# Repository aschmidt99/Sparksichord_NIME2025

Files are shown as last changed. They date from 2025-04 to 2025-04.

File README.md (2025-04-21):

# Sparksichord_NIME2025
 A repo for schematics, CAD, and audiovisual examples to accompany the NIME 2025 Sparksichord conference paper by Adam Schmidt, Jeffrey Snyder, Gian Torrano Jacobs, Joseph Gascho, Joyce Chen, and Andrew McPherson.

 Primary contact: a.schmidt24@imperial.ac.uk

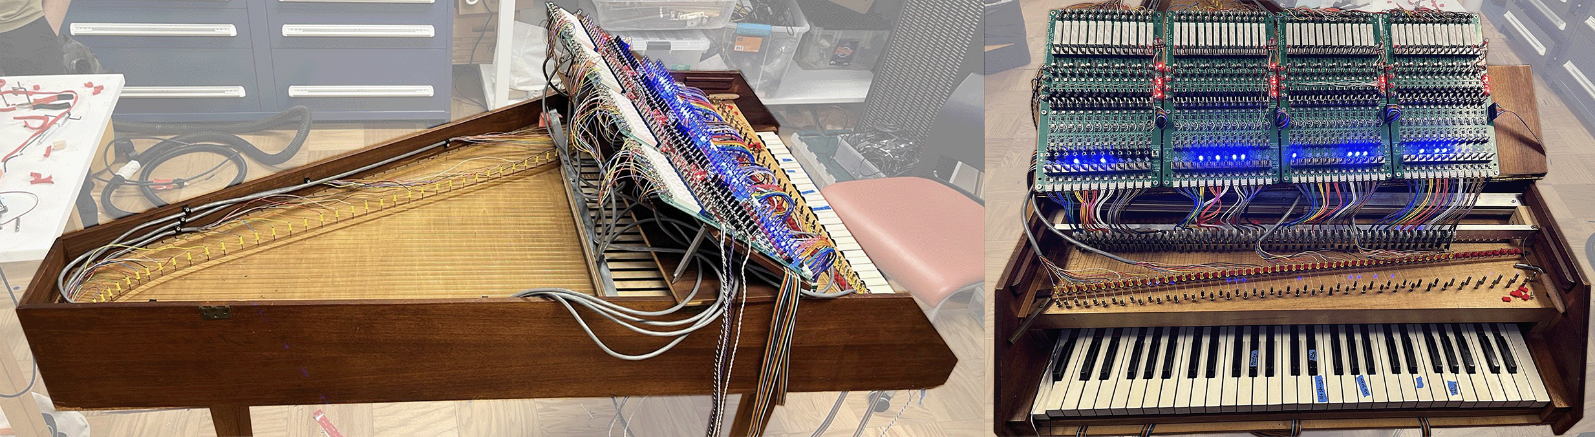
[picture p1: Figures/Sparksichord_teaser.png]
EM_Harpsichord

The Sparksichord is a practical implementation of a 4-octave/48-channel Lorentz Force feedback sustainer system using brass strings, permanent magnets, optical sensors, and custom analog electronics. The Sparksichord is an augmentation of a 1970’s Zuckermann ‘Z-Box’ Harpsichord and uses its own keyboard to control the volume of each string’s feedback/actuation. Here we provide a basic overview of the working principles of the Sparksichord. For a more comprehensive guide to Lorentz Force actuation, please see _The Sparksichord: Practical Implementation of a Lorentz Force Electromagnetic Actuation and Feedback System_.

## Audiovisual example:
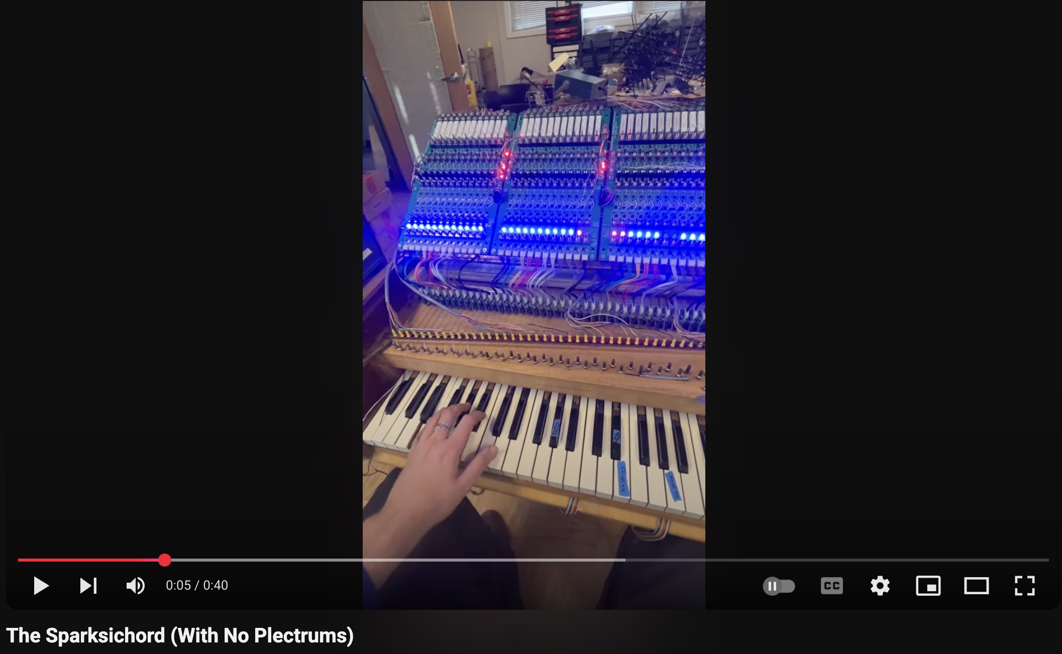
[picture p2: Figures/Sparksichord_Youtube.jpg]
Sparksichord Youtube Clip (https://www.youtube.com/watch?v=jK8IH_FwZ0k)


# Lorentz Force
The cumulative force felt by a charged particle exposed to electric and magnetic fields is known as the _Lorentz Force_. A special case of the Lorentz Force (sometimes referred to as the _Laplace Force_) describes the magnetic force felt by a current-carrying wire exposed to a magnetic field:

$$
\begin{align}
 \mathbf{F} = I \mathbf{L} \times \mathbf{B}
\end{align}
$$

where $\mathbf{F}$ is the force vector felt by the wire, $I$ is the current through the wire, $\mathbf{B}$ is the magnetic field vector, and $\mathbf{L}$ is the length of the wire exposed to the magnetic field.

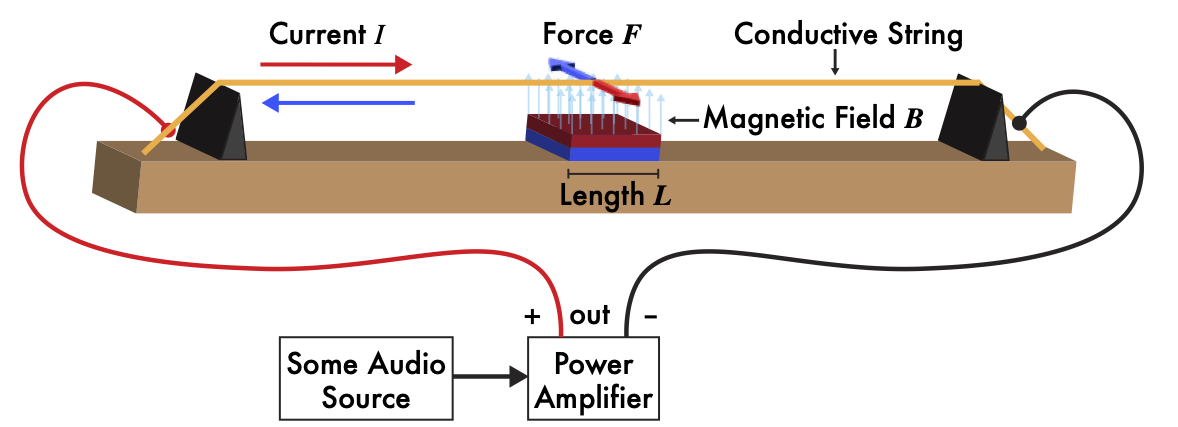
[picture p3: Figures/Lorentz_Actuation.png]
Lorentz Force Overview


Inputing an audio signal to the string such as white noise, you should hear the string vibrate most prominently at its natural resonant frequencies. It is possible to drive a string with an oscillator tuned to match the string’s fundamental frequency, but doing so can be tricky. Depending on the material properties of the actuated string, some of the actuation current may be dissipated as heat in the string’s internal resistance, introducing thermal expansion of the string and causing it to lengthen and reduce its tension. This brings the frequency of the string down causing it to no longer match the frequency of the open-loop actuation signal.

## Heat Buildup \& String Detuning

The resistivity of some conductive metals are displayed in the figure below. Metals such as yellow and red brass are much less resistive than iron and steel, meaning they are more robust to string detuning, though it should be noted that heat treatment or work-hardening of the string material is also a factor, where annealed metal will typically have higher conductivity than a heat-treated metal. Heat-treating or other processes that increase the stength of a metal string are often required for strings to withstand the tensions typically found in musical instruments, so it is fair to assume any wire intended for stringing instruments will have slightly greater resistivity than in the figure below.

Conductivity

The intensity of detuning is proportional to its heat buildup and therefore proportional to the resistivity inherent to the string:

$$
\begin{align}
  Q = I^2Rt
\end{align}
$$

where $Q$ = heat buildup, $I$ = electric current, $R$ = resistance, and $t$ = time. Though this formula suggests that the string may heat up and continue to detune indefinitely as electric current is applied, there is an element of heat dissipation into the surrounding air and any other materials the string is in contact with.  In other words, for a real system, the detuning effect from heat buildup eventually finds equilibrium with the heat dissipation, stabilizing the tuning for a given electric current at a given room temperature.

# Lorentz Force Feedback via Optical Sensor
An optical sensor (in our case, the ITR20403) can be used to sense the string's position. If this signal is sent back into the string via a power amplifier, the string should begin to feedback.
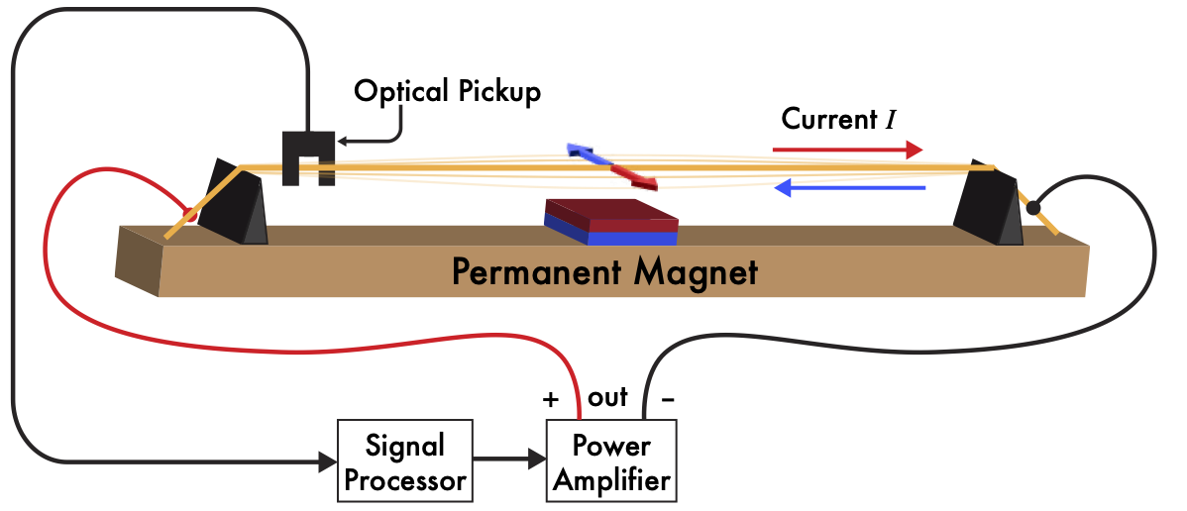
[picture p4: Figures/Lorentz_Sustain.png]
Lorentz Force Feedback via Optical Sensor


On the Sparksichord, an array of 48 sensors was placed above the strings.
Optical Sensor Array

# Dynamic Control Via Amplitude Limitation
We can control the feedback volume by introducing a voltage-controlled limiter. On the Sparksichord, the limiter control signal can from the instrument's own keys (see next section), an onboard potentiometer, or an external control voltage source.
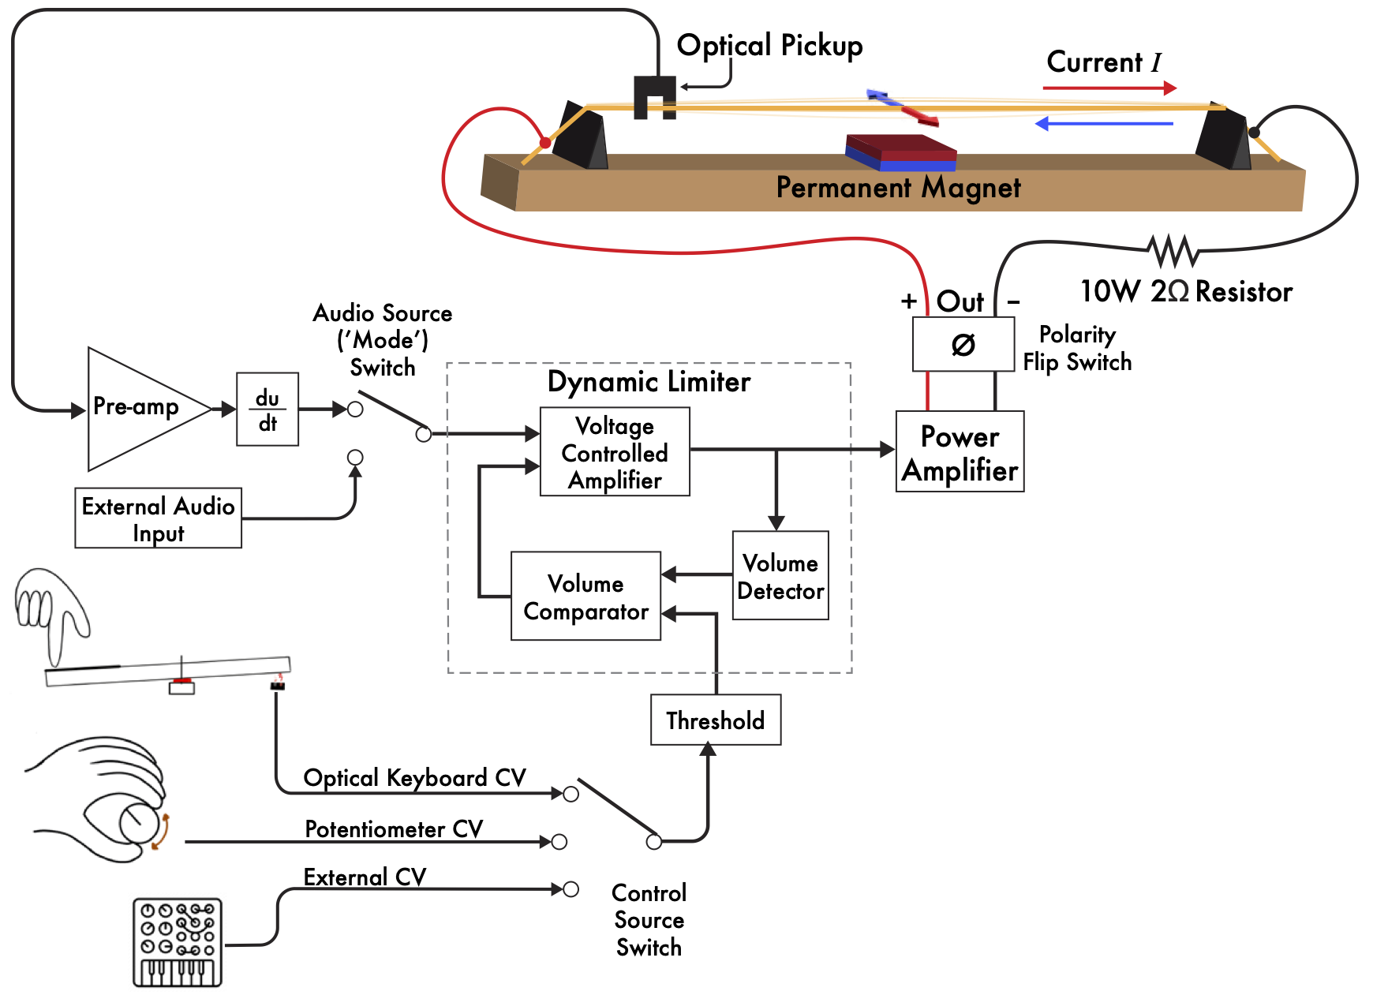
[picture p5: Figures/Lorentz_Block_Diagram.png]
Amplitude Limitation


# Controlling Feedback with Keyboard
To capture how far each key is pressed (to set each limiter circuit's threshold value), we use an array of QRD1114 Optical sensors placed at the back of the keyboard:
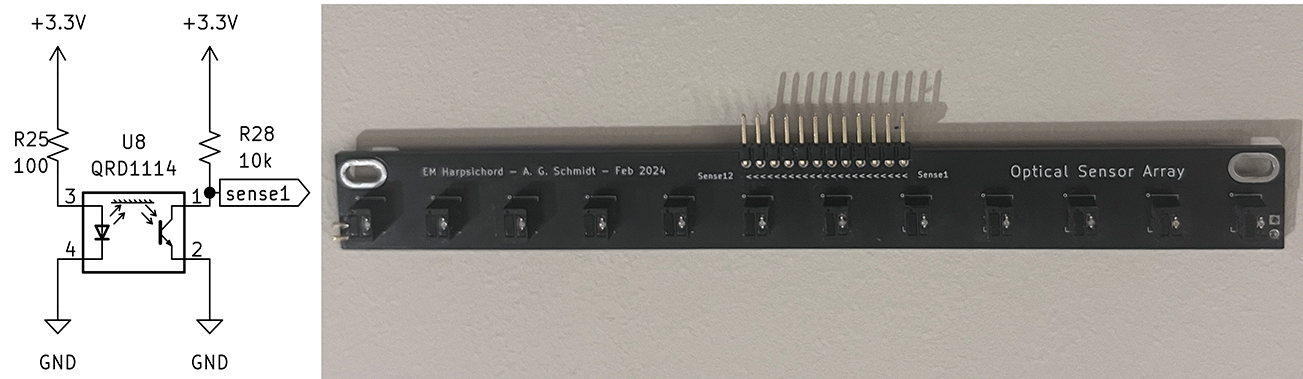
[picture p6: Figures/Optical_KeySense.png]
Optical Keyboard Sensors

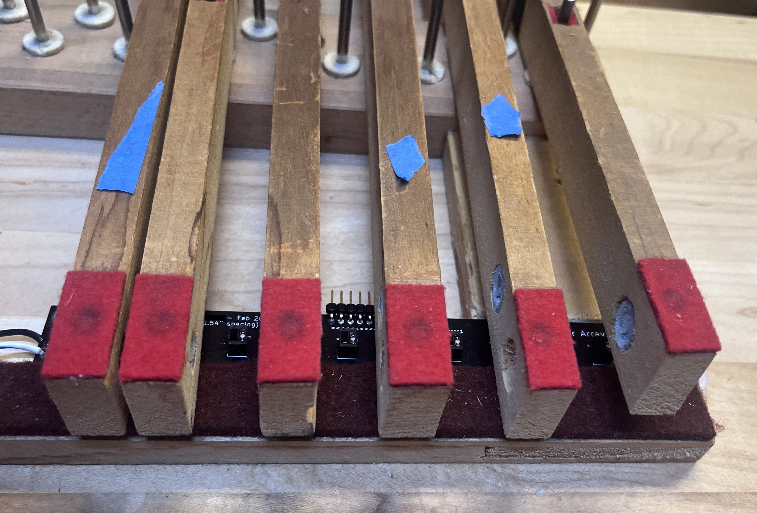
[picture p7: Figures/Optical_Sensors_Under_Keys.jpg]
Optical Sensors Under Keys


# 12-Channel PCB
There are four of these 12-channel sustainer control boards on the Sparksichord:
Optical Sensors Under Keys

# Magnet Placement
Running AC signal through a string doesn't make the string vibrate unless there is a magnetic field nearby. To create a relatively uniform magnetic field for all of the strings, we created a rail that holds 24 N52 Neodymium magnets in uniformly-spaced slots. The position of each magnet can be adjusted to find a desirable feedback timbre:
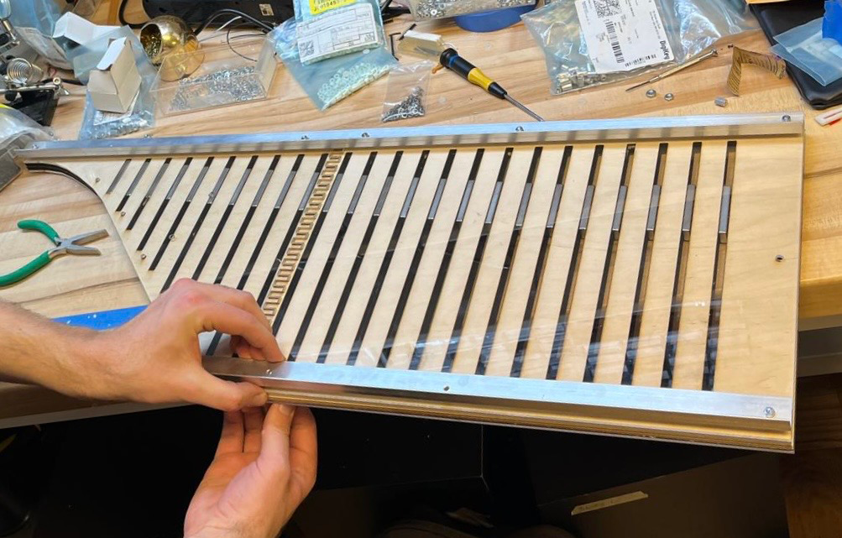
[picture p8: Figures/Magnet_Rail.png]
Magnet Rail

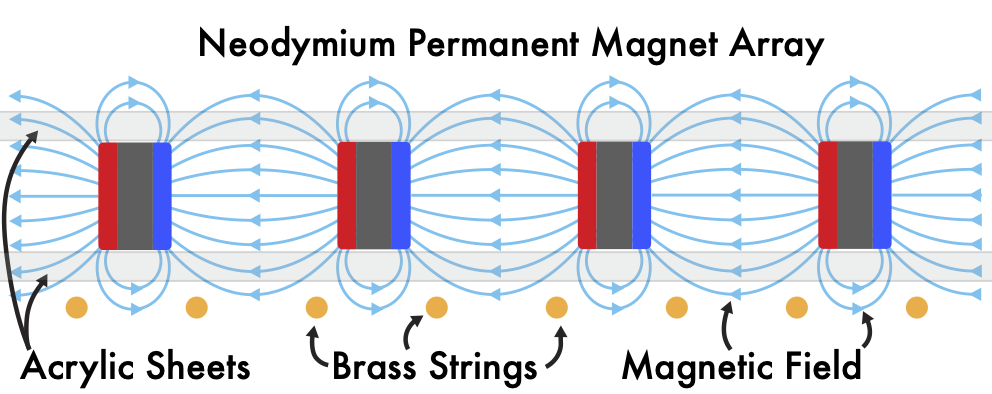
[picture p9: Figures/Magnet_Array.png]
Magnetic Field


# Acknowledgements
This work was supported by a UKRI Frontier Research (Consolidator) grant (EP/X023478/1) “RUDIMENTS: Reflective Understanding of Digital Instruments as Musical Entanglements” and by the Royal Academy of Engineering under the Research Chairs and Senior Research Fellowships scheme.
Early development of this work was supported in part by the University of Michigan Organ Department, University of Michigan ArtsEngine Arts Integrative Interdisciplinary Research (AiiR) Grant, and the University of Michigan EXCEL Enterprise Grant.

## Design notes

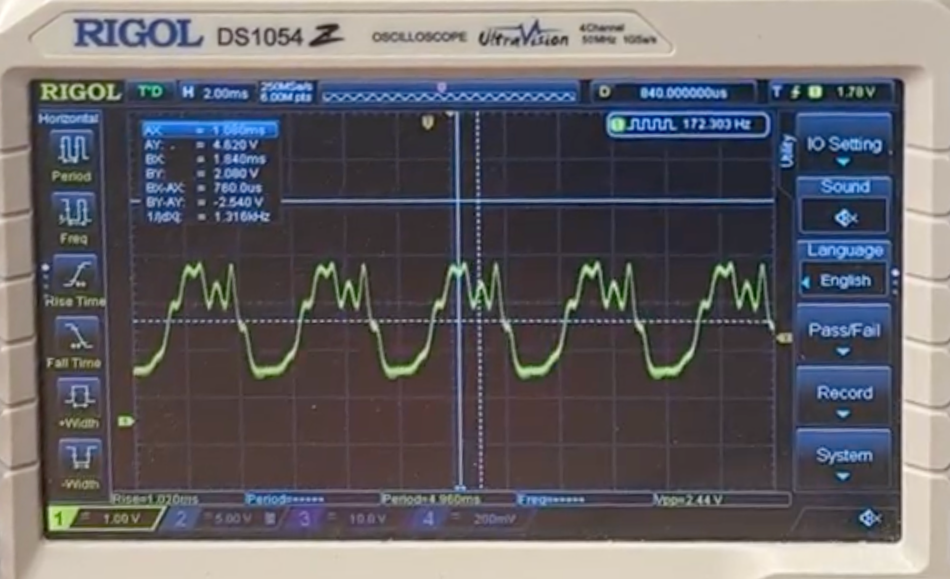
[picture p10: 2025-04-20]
Figures/OpticalSensorDuringFeedback.png

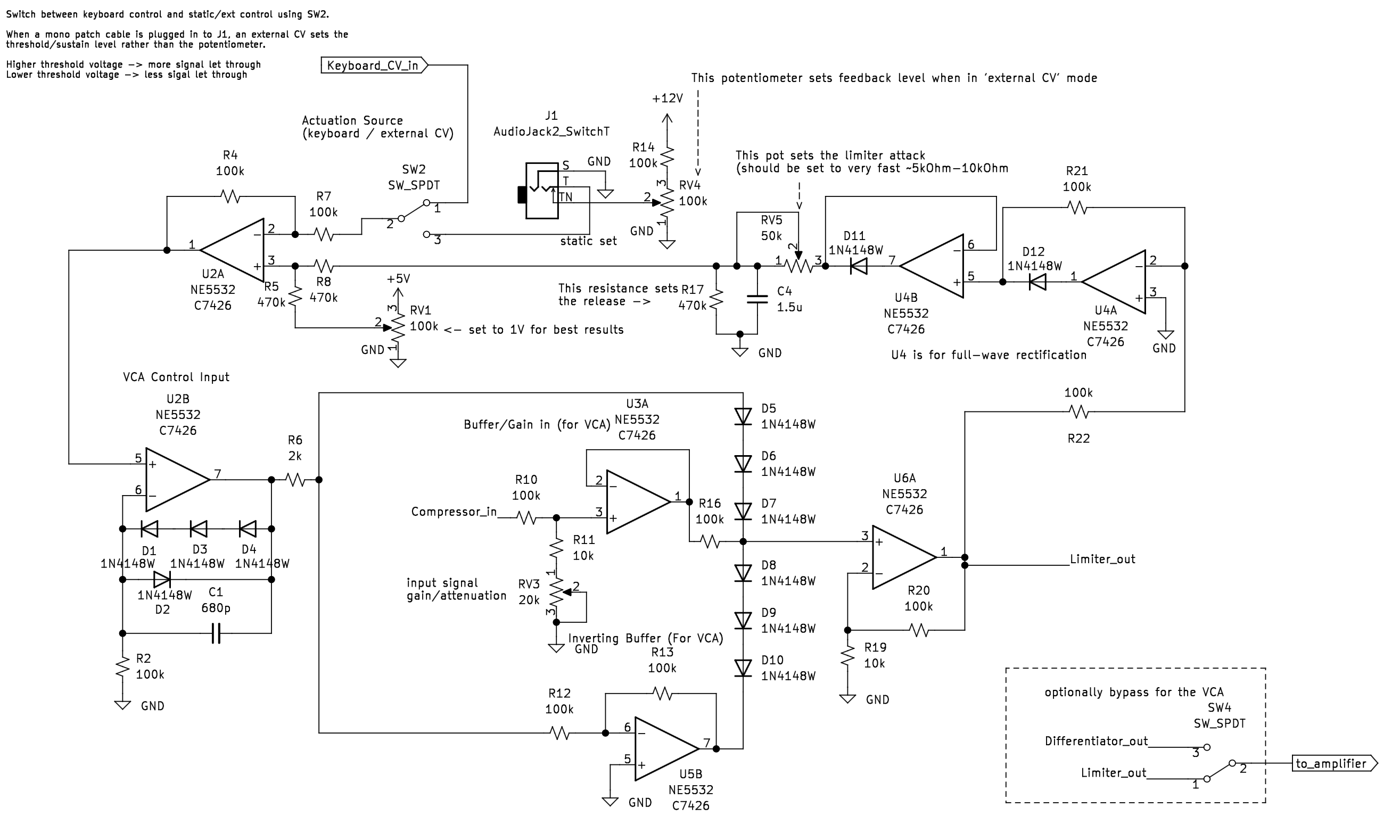
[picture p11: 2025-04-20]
Figures/LimiterCircuit.png

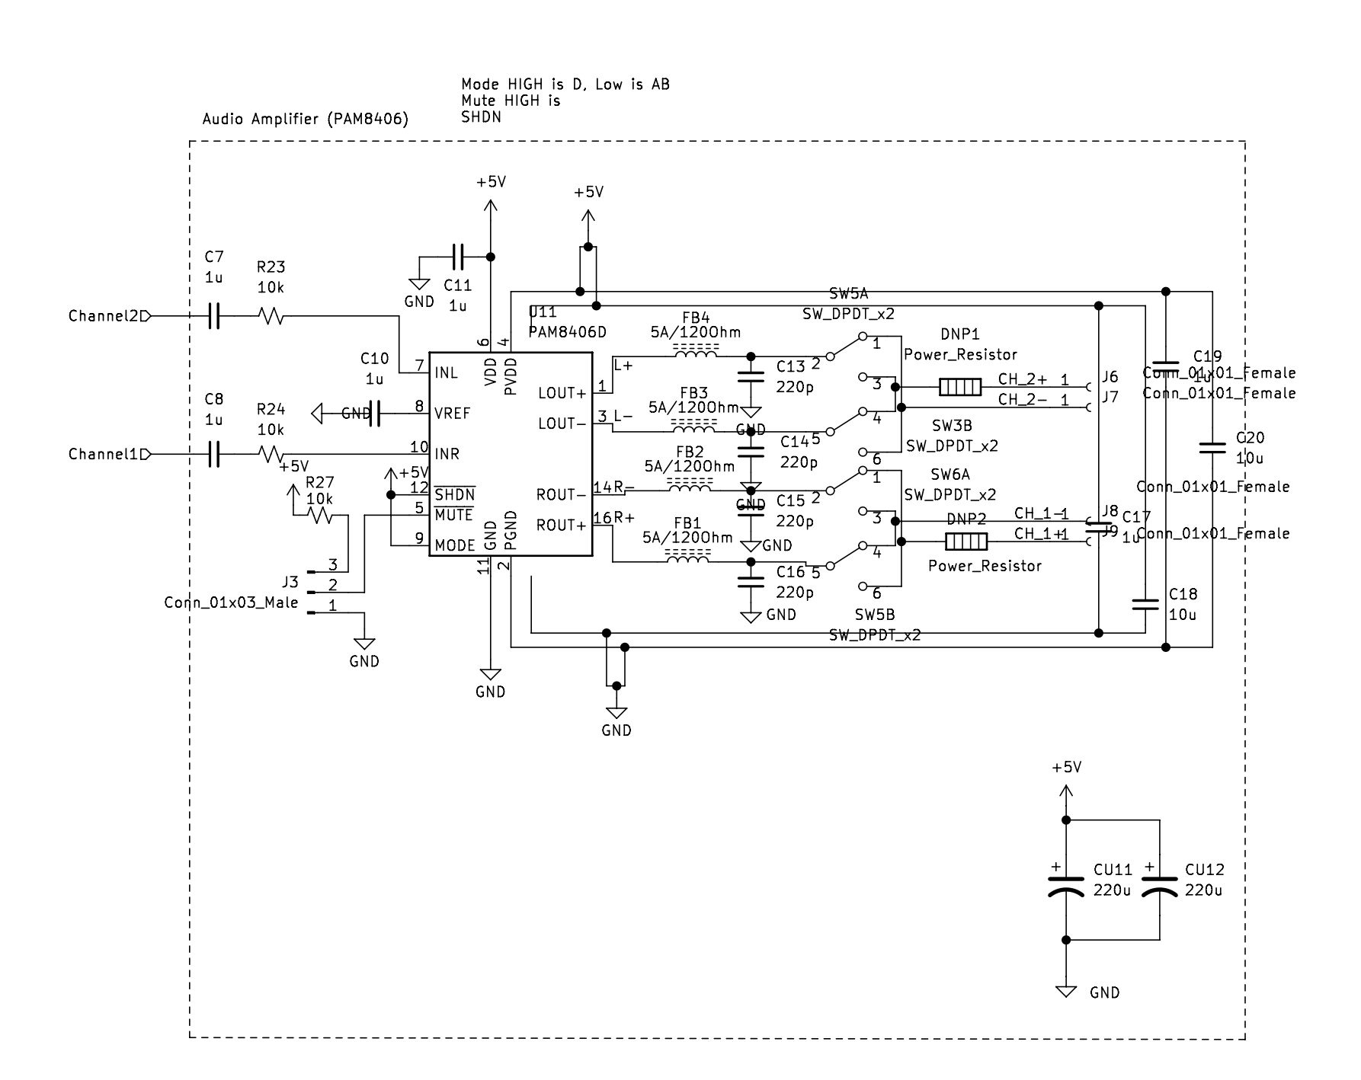
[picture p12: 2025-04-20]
Figures/PAM8406.png

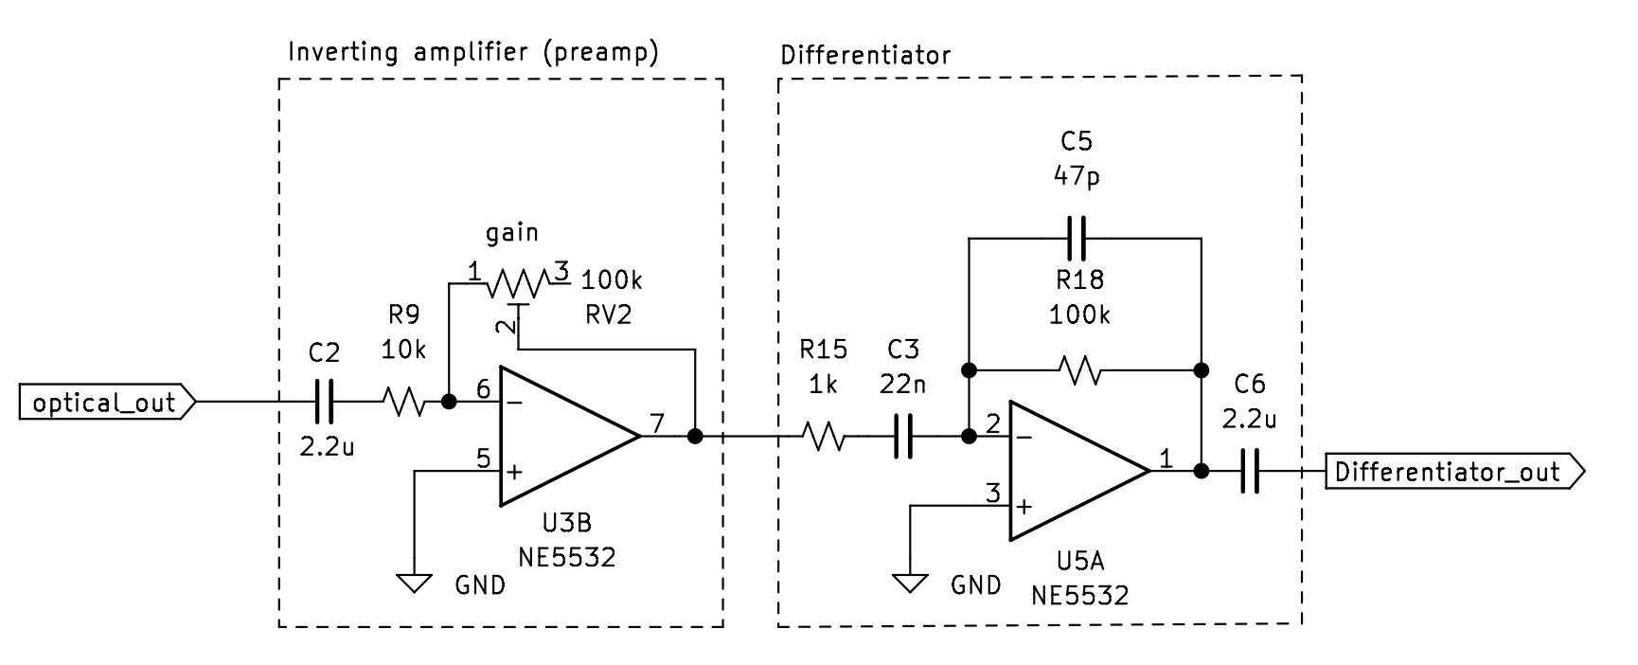
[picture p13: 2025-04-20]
Figures/Gain_Diff.png

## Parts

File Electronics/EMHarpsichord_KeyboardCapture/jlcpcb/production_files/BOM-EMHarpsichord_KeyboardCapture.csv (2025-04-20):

Comment | Designator | Footprint | LCSC
10k | R20 | R_0603_1608Metric
10k | R8 | R_0603_1608Metric
100 | R9 | R_0603_1608Metric
10k | R22 | R_0603_1608Metric
10k | R6 | R_0603_1608Metric
Conn_01x02_Male | J3 | PinHeader_1x02_P2.54mm_Vertical
10k | R14 | R_0603_1608Metric
MountPad1 | MP1 | MountingHole_4.3mm_M4_ISO7380_Pad
100 | R17 | R_0603_1608Metric
10k | R12 | R_0603_1608Metric
1u | C2 | C_0603_1608Metric
LED | D2 | LED_0603_1608Metric
100 | R25 | R_0603_1608Metric
100 | R15 | R_0603_1608Metric
100 | R5 | R_0603_1608Metric
10k | R24 | R_0603_1608Metric
TLV75510PDBV | U13 | SOT-23-5
Conn_01x02_Female | J2 | PinHeader_1x02_P2.54mm_Vertical
100 | R21 | R_0603_1608Metric
SolderJumper_2_Bridged | JP1 | SolderJumper-2_P1.3mm_Bridged_RoundedPad1.0x1.5mm
10k | R16 | R_0603_1608Metric
10k | R2 | R_0603_1608Metric
100 | R11 | R_0603_1608Metric
100 | R19 | R_0603_1608Metric
100 | R3 | R_0603_1608Metric
10k | R10 | R_0603_1608Metric
100 | R13 | R_0603_1608Metric
MountPad2 | MP2 | MountingHole_4.3mm_M4_ISO7380_Pad
Conn_01x12_Female | J1 | PinHeader_1x12_P2.54mm_Vertical
100 | R23 | R_0603_1608Metric
10k | R4 | R_0603_1608Metric
1u | C1 | C_0603_1608Metric
1N4001 | D1 | D_SOD-123
10k | R18 | R_0603_1608Metric
100 | R1 | R_0603_1608Metric
100 | R7 | R_0603_1608Metric
QRD1114 | U5 | OnSemi_QRD1114
QRD1114 | U12 | OnSemi_QRD1114
QRD1114 | U2 | OnSemi_QRD1114
QRD1114 | U3 | OnSemi_QRD1114
QRD1114 | U10 | OnSemi_QRD1114
QRD1114 | U8 | OnSemi_QRD1114
QRD1114 | U11 | OnSemi_QRD1114
QRD1114 | U1 | OnSemi_QRD1114
QRD1114 | U6 | OnSemi_QRD1114
QRD1114 | U9 | OnSemi_QRD1114
QRD1114 | U7 | OnSemi_QRD1114
QRD1114 | U4 | OnSemi_QRD1114

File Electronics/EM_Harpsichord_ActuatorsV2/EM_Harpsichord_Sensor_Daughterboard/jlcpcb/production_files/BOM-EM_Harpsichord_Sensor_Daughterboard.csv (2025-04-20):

Comment | Designator | Footprint | LCSC
Conn_01x03_Male | J1 | JST_XH_S3B-XH-A_1x03_P2.50mm_Horizontal | C161870
ITR20403 | U1 | Everlight_ITR20403 | C5135
PT_out | TP3 | TestPoint_THTPad_D2.0mm_Drill1.0mm
MountingHole | TP2 | TestPoint_THTPad_D2.0mm_Drill1.0mm
0 | R2 | R_0603_1608Metric
DNP | R4 | R_0603_1608Metric
220 | R1 | R_0603_1608Metric
PT_out | TP1 | TestPoint_THTPad_D2.0mm_Drill1.0mm
20k | R3 | R_0603_1608Metric

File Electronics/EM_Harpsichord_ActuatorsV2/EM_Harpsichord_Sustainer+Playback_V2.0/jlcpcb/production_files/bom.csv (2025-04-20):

Comment | Designator | Footprint | LCSC
Conn_01x03_Male | J17,J20,J23,J26,J29,J3,J32,J35,J38,J41,J44,J47 | JST_XH_S3B-XH-A_1x03_P2.50mm_Horizontal | C157928
220u | CU11,CU12,CU123,CU124,CU125,CU126,CU127,CU128,CU129,CU130,CU131,CU132 | C_Elec_6.3x5.8 | C497579
1N4148W | D1,D10,D100,D101,D102,D103,D104,D105,D106,D107,D108,D11,D110,D111,D112,D113,D114,D115,D116,D117,D118,D119,D120,D122,D123,D124,D125,D126,D127,D128,D129,D130,D131,D132,D134,D135,D136,D137,D138,D139,D14,D140,D141,D142,D143,D144,D15,D16,D17,D18,D19,D2,D20,D21,D22,D23,D24,D26,D27,D28,D29,D3,D30,D31,D32,D33,D34,D35,D36,D38,D39,D4,D40,D41,D42,D43,D44,D45,D46,D47,D48,D5,D50,D51,D52,D53,D54,D55,D56,D57,D58,D59,D6,D60,D62,D63,D64,D65,D66,D67,D68,D69,D7,D70,D71,D72,D74,D75,D76,D77,D78,D79,D8,D80,D81,D82,D83,D84,D86,D87,D88,D89,D9,D90,D91,D92,D93,D94,D95,D96,D98,D99 | D_SOD-123 | C5345962
LED | D145,D146,D147 | LED_0603_1608Metric | C601667
50k | RV11,RV17,RV23,RV29,RV35,RV4,RV41,RV47,RV53,RV59,RV65,RV71 | Potentiometer_Bourns_3314G_Vertical | C719184
NE5532 | U1,U101,U102,U103,U104,U105,U11,U111,U112,U113,U114,U115,U12,U13,U14,U15,U2,U21,U22,U23,U24,U25,U3,U31,U32,U33,U34,U35,U4,U41,U42,U43,U44,U45,U5,U51,U52,U53,U54,U55,U61,U62,U63,U64,U65,U71,U72,U73,U74,U75,U81,U82,U83,U84,U85,U91,U92,U93,U94,U95 | SOP-8_3.76x4.96mm_P1.27mm | C7426
20k | RV15,RV2,RV21,RV27,RV33,RV39,RV45,RV51,RV57,RV63,RV69,RV9 | Potentiometer_Bourns_3314G_Vertical | C780217
100k | RV1,RV12,RV13,RV14,RV18,RV19,RV20,RV24,RV25,RV26,RV3,RV30,RV31,RV32,RV36,RV37,RV38,RV42,RV43,RV44,RV48,RV49,RV50,RV54,RV55,RV56,RV6,RV60,RV61,RV62,RV66,RV67,RV68,RV7,RV72,RV8 | Potentiometer_Bourns_3314G_Vertical | C780219
PAM8406D | U17,U27,U307,U407,U507,U7 | SOP-16_3.9x9.9mm_P1.27mm | C86270
100n | CU116 | C_0603_1608Metric
100k | R70 | R_0603_1608Metric
Conn_01x01_Female | J66 | TerminalBlock_Keystone_7797
1u | C88 | C_0603_1608Metric
diff_out_a | TP82 | TestPoint_THTPad_D2.0mm_Drill1.0mm
MountingHole | TP86 | MountingHole_4.3mm_M4
100k | R181 | R_0603_1608Metric
gain_out | TP95 | TestPoint_THTPad_D2.0mm_Drill1.0mm
Conn_01x01_Female | J61 | TerminalBlock_Keystone_7797
100k | R54 | R_0603_1608Metric
2k | R165 | R_0603_1608Metric
1u | C134 | C_0603_1608Metric
100n | CU6 | C_0603_1608Metric
comp_out_b | TP15 | TestPoint_THTPad_D2.0mm_Drill1.0mm
1u | C85 | C_0603_1608Metric
100n | CU35 | C_0603_1608Metric
2k | R36 | R_0603_1608Metric
10k | R145 | R_0603_1608Metric
100n | CU40 | C_0603_1608Metric
100k | R302 | R_0603_1608Metric
1k | R150 | R_0603_1608Metric
Conn_01x01_Female | J14 | TerminalBlock_Keystone_7797
100k | R85 | R_0603_1608Metric
100k | R252 | R_0603_1608Metric
10k | R40 | R_0603_1608Metric
0 | R136 | R_0603_1608Metric
430 | R134 | R_0603_1608Metric
100n | CU34 | C_0603_1608Metric
100n | CU2 | C_0603_1608Metric
100n | CU33 | C_0603_1608Metric
100k | R5 | R_0603_1608Metric
22n | C45 | C_0603_1608Metric
SW_SPDT | SW18 | SW_submini_SPST
100n | CU14 | C_0603_1608Metric
AudioJack2_SwitchT | J46 | Jack_3.5mm_QingPu_WQP-PJ301M-12_Vertical
SW_DPDT_x2 | SW106 | SW_standard_DPDT_MTS
100n | CU120 | C_0603_1608Metric
MountingHole | TP89 | MountingHole_4.3mm_M4_DIN965_Pad
1.5u | C28 | C_0603_1608Metric
100k | R14 | R_0603_1608Metric
LED_Dual_KAK | D109 | LED_D3.0mm-3
comp_out_a | TP13 | TestPoint_THTPad_D2.0mm_Drill1.0mm
100k | R303 | R_0603_1608Metric
10k | R284 | R_0603_1608Metric
10k | R310 | R_0603_1608Metric
100k | R20 | R_0603_1608Metric
Conn_01x03_Male | J59 | PinHeader_1x03_P2.54mm_Vertical
SW_DPDT_x2 | SW24 | SW_standard_DPDT_MTS
100n | CU43 | C_0603_1608Metric
100n | CU47 | C_0603_1608Metric
SW_SPDT | SW26 | SW_submini_SPST
comp_out_a | TP20 | TestPoint_THTPad_D2.0mm_Drill1.0mm
470k | R116 | R_0603_1608Metric
comp_out_b | TP85 | TestPoint_THTPad_D2.0mm_Drill1.0mm
1u | C11 | C_0603_1608Metric
100k | R288 | R_0603_1608Metric
0 | R292 | R_0603_1608Metric
100k | R101 | R_0603_1608Metric
100k | R294 | R_0603_1608Metric
100k | R48 | R_0603_1608Metric
diff_out_b | TP28 | TestPoint_THTPad_D2.0mm_Drill1.0mm
MountingHole | TP92 | MountingHole_4.3mm_M4
SW_SPDT | SW40 | SW_submini_SPST
0 | R213 | R_0603_1608Metric
1u | C131 | C_0603_1608Metric
10k | R322 | R_0603_1608Metric
100k | R73 | R_0603_1608Metric
220p | C113 | C_0603_1608Metric
100n | CU4 | C_0603_1608Metric
ADJ | R100 | R_0603_1608Metric
1u | C19 | C_0603_1608Metric
1.5u | C40 | C_0603_1608Metric
2.2u | C32 | C_0603_1608Metric
100n | CU90 | C_0603_1608Metric
2.2u | C60 | C_0603_1608Metric
1u | C143 | C_0603_1608Metric
470k | R279 | R_0603_1608Metric
510 | R107 | R_0603_1608Metric
100k | R4 | R_0603_1608Metric
470k | R220 | R_0603_1608Metric
100k | R173 | R_0603_1608Metric
diff_out | TP37 | TestPoint_THTPad_D2.0mm_Drill1.0mm
Conn_01x01_Female | J68 | TerminalBlock_Keystone_7797
10k | R258 | R_0603_1608Metric
Power_Resistor | DNP9 | R_Axial_Power_L50.0mm_W9.0mm_P55.88mm
100k | RV22 | Potentiometer_Bourns_PTV09A-1_Single_Vertical
510 | R289 | R_0603_1608Metric
100k | R125 | R_0603_1608Metric
LED_Dual_KAK | D85 | LED_D3.0mm-3
1u | C123 | C_0603_1608Metric
5A/120Ohm | FB9 | C_0805_2012Metric
510 | R133 | R_0603_1608Metric
AudioJack2_SwitchT | J48 | Jack_3.5mm_QingPu_WQP-PJ301M-12_Vertical
100n | CU36 | C_0603_1608Metric
Power_Resistor | DNP6 | R_Axial_Power_L50.0mm_W9.0mm_P55.88mm
SW_DPDT_x2 | SW104 | SW_standard_DPDT_MTS
100n | CU72 | C_0603_1608Metric
comp_out_b | TP36 | TestPoint_THTPad_D2.0mm_Drill1.0mm
AudioJack2_SwitchT | J21 | Jack_3.5mm_QingPu_WQP-PJ301M-12_Vertical
100n | CU32 | C_0603_1608Metric
100k | R138 | R_0603_1608Metric
100n | CU118 | C_0603_1608Metric
SW_SPDT | SW23 | SW_submini_SPST
100k | R177 | R_0603_1608Metric
20k | R312 | R_0603_1608Metric
100n | CU89 | C_0603_1608Metric
gain_out | TP94 | TestPoint_THTPad_D2.0mm_Drill1.0mm
100k | R313 | R_0603_1608Metric
2.2u | C24 | C_0603_1608Metric
AudioJack2_SwitchT | J18 | Jack_3.5mm_QingPu_WQP-PJ301M-12_Vertical
SW_SPDT | SW17 | SW_submini_SPST
100k | R210 | R_0603_1608Metric
100n | CU73 | C_0603_1608Metric
1u | C121 | C_0603_1608Metric
1u | C110 | C_0603_1608Metric
Conn_01x03_Male | J69 | PinHeader_1x03_P2.54mm_Vertical
diff_out_a | TP61 | TestPoint_THTPad_D2.0mm_Drill1.0mm
10k | R91 | R_0603_1608Metric
Conn_01x03_Male | J64 | PinHeader_1x03_P2.54mm_Vertical
Conn_01x01_Female | J52 | TerminalBlock_Keystone_7797
2k | R243 | R_0603_1608Metric
1u | C100 | C_0603_1608Metric
SW_DPDT_x2 | SW305 | SW_standard_DPDT_MTS
510 | R263 | R_0603_1608Metric
100n | CU97 | C_0603_1608Metric
diff_out_a | TP33 | TestPoint_THTPad_D2.0mm_Drill1.0mm
gain_out | TP96 | TestPoint_THTPad_D2.0mm_Drill1.0mm
100k | R198 | R_0603_1608Metric
470k | R246 | R_0603_1608Metric
gain_out | TP52 | TestPoint_THTPad_D2.0mm_Drill1.0mm
0 | R26 | R_0603_1608Metric
47p | C65 | C_0603_1608Metric
10k | R317 | R_0603_1608Metric
100k | R257 | R_0603_1608Metric
100n | CU65 | C_0603_1608Metric
Conn_01x01_Female | J60 | TerminalBlock_Keystone_7797
100k | RV52 | Potentiometer_Bourns_PTV09A-1_Single_Vertical
20k | R104 | R_0603_1608Metric
22n | C69 | C_0603_1608Metric
gain_out | TP24 | TestPoint_THTPad_D2.0mm_Drill1.0mm
100n | CU99 | C_0603_1608Metric
100k | R250 | R_0603_1608Metric
1u | C124 | C_0603_1608Metric
1u | C86 | C_0603_1608Metric
220p | C92 | C_0603_1608Metric
SW_SPDT | SW3 | SW_submini_SPST
diff_out | TP65 | TestPoint_THTPad_D2.0mm_Drill1.0mm
diff_out_b | TP56 | TestPoint_THTPad_D2.0mm_Drill1.0mm
100n | CU59 | C_0603_1608Metric
LED_Dual_KAK | D12 | LED_D3.0mm-3
gain_out | TP45 | TestPoint_THTPad_D2.0mm_Drill1.0mm
10k | R318 | R_0603_1608Metric
SW_SPDT | SW13 | SW_submini_SPST
100n | CU122 | C_0603_1608Metric
100k | R75 | R_0603_1608Metric
470k | R39 | R_0603_1608Metric
AudioJack2_SwitchT | J34 | Jack_3.5mm_QingPu_WQP-PJ301M-12_Vertical
20k | R260 | R_0603_1608Metric
diff_out | TP79 | TestPoint_THTPad_D2.0mm_Drill1.0mm
gain_out | TP38 | TestPoint_THTPad_D2.0mm_Drill1.0mm
100n | CU13 | C_0603_1608Metric
100k | R216 | R_0603_1608Metric
100n | CU52 | C_0603_1608Metric
SW_SPDT | SW28 | SW_submini_SPST
22n | C2 | C_0603_1608Metric
diff_out | TP72 | TestPoint_THTPad_D2.0mm_Drill1.0mm
220p | C91 | C_0603_1608Metric
0 | R110 | R_0603_1608Metric
10k | R6 | R_0603_1608Metric
10k | R102 | R_0603_1608Metric
AudioJack2_SwitchT | J42 | Jack_3.5mm_QingPu_WQP-PJ301M-12_Vertical
680p | C55 | C_0603_1608Metric
20k | R182 | R_0603_1608Metric
AudioJack2_SwitchT | J43 | Jack_3.5mm_QingPu_WQP-PJ301M-12_Vertical
ADJ | R15 | R_0603_1608Metric
Conn_01x01_Female | J9 | TerminalBlock_Keystone_7797
10k | R197 | R_0603_1608Metric
100n | CU93 | C_0603_1608Metric
10u | C130 | C_0805_2012Metric
10k | R66 | R_0603_1608Metric
1k | R98 | R_0603_1608Metric
diff_out_a | TP26 | TestPoint_THTPad_D2.0mm_Drill1.0mm
100k | R22 | R_0603_1608Metric
10k | R143 | R_0603_1608Metric
AudioJack3 | JA1_in1 | Jack_3.5mm_QingPu_WQP-PJ366ST_Vertical
10k | R273 | R_0603_1608Metric
10k | R323 | R_0603_1608Metric
220p | C125 | C_0603_1608Metric
PD_out | TP18 | TestPoint_THTPad_D2.0mm_Drill1.0mm
100n | CU9 | C_0603_1608Metric
100k | R50 | R_0603_1608Metric
diff_out | TP51 | TestPoint_THTPad_D2.0mm_Drill1.0mm
Conn_01x01_Female | J2 | TerminalBlock_Keystone_7797
100n | CU62 | C_0603_1608Metric
470k | R305 | R_0603_1608Metric
100k | R67 | R_0603_1608Metric
430 | R24 | R_0603_1608Metric
diff_out_b | TP70 | TestPoint_THTPad_D2.0mm_Drill1.0mm
100k | R9 | R_0603_1608Metric
100k | R131 | R_0603_1608Metric
100n | CU20 | C_0603_1608Metric
PD_out | TP25 | TestPoint_THTPad_D2.0mm_Drill1.0mm
100n | CU49 | C_0603_1608Metric
SW_DPDT_x2 | SW84 | SW_standard_DPDT_MTS
Conn_01x01_Female | J65 | TerminalBlock_Keystone_7797
100n | CU92 | C_0603_1608Metric
100k | R225 | R_0603_1608Metric
0 | R32 | R_0603_1608Metric
gain_out | TP104 | TestPoint_THTPad_D2.0mm_Drill1.0mm
LED_Dual_KAK | D49 | LED_D3.0mm-3
10k | R299 | R_0603_1608Metric
100n | CU87 | C_0603_1608Metric
SW_SPDT | SW36 | SW_submini_SPST
Power_Resistor | DNP4 | R_Axial_Power_L50.0mm_W9.0mm_P55.88mm
AudioJack2_SwitchT | J40 | Jack_3.5mm_QingPu_WQP-PJ301M-12_Vertical
100n | CU22 | C_0603_1608Metric
100k | R17 | R_0603_1608Metric
1.5u | C70 | C_0603_1608Metric
100n | CU121 | C_0603_1608Metric
100n | CU113 | C_0603_1608Metric
10k | R249 | R_0603_1608Metric
1u | C93 | C_0603_1608Metric
1u | C122 | C_0603_1608Metric
1.5u | C76 | C_0603_1608Metric
Conn_01x03_Male | J49 | PinHeader_1x03_P2.54mm_Vertical
10k | R169 | R_0603_1608Metric
0 | R187 | R_0603_1608Metric
100k | R278 | R_0603_1608Metric
0 | R162 | R_0603_1608Metric
10k | R180 | R_0603_1608Metric
Conn_01x01_Female | J6 | TerminalBlock_Keystone_7797
Conn_01x12_Female | J5 | PinHeader_1x12_P2.54mm_Vertical
5A/120Ohm | FB8 | C_0805_2012Metric
1u | C12 | C_0603_1608Metric
10k | R28 | R_0603_1608Metric
100k | R287 | R_0603_1608Metric
100n | CU51 | C_0603_1608Metric
AudioJack3 | JA2_out1 | Jack_3.5mm_QingPu_WQP-PJ366ST_Vertical
AudioJack2_SwitchT | J200 | Jack_3.5mm_QingPu_WQP-PJ301M-12_Vertical
100k | R293 | R_0603_1608Metric
PD_out | TP53 | TestPoint_THTPad_D2.0mm_Drill1.0mm
1.5u | C82 | C_0603_1608Metric
diff_out_a | TP12 | TestPoint_THTPad_D2.0mm_Drill1.0mm
100k | R315 | R_0603_1608Metric
470k | R296 | R_0603_1608Metric
gain_out | TP31 | TestPoint_THTPad_D2.0mm_Drill1.0mm
10u | C108 | C_0805_2012Metric
100k | R118 | R_0603_1608Metric
Conn_01x03_Male | J1 | PinHeader_1x03_P2.54mm_Vertical
100k | R115 | R_0603_1608Metric
510 | R211 | R_0603_1608Metric
1k | R254 | R_0603_1608Metric
100k | R38 | R_0603_1608Metric
gain_out | TP93 | TestPoint_THTPad_D2.0mm_Drill1.0mm
5A/120Ohm | FB19 | C_0805_2012Metric
10k | R206 | R_0603_1608Metric
100k | RV34 | Potentiometer_Bourns_PTV09A-1_Single_Vertical
100k | R52 | R_0603_1608Metric
5A/120Ohm | FB18 | C_0805_2012Metric
comp_out_a | TP76 | TestPoint_THTPad_D2.0mm_Drill1.0mm
100n | CU42 | C_0603_1608Metric
470k | R168 | R_0603_1608Metric
SW_SPDT | SW21 | SW_submini_SPST
AudioJack2_SwitchT | J24 | Jack_3.5mm_QingPu_WQP-PJ301M-12_Vertical
Power_Resistor | DNP2 | R_Axial_Power_L50.0mm_W9.0mm_P55.88mm
10u | C20 | C_0805_2012Metric
100n | CU45 | C_0603_1608Metric
PD_out | TP67 | TestPoint_THTPad_D2.0mm_Drill1.0mm
100k | R10 | R_0603_1608Metric
SW_SPDT | SW32 | SW_submini_SPST
100k | R158 | R_0603_1608Metric
10k | R171 | R_0603_1608Metric
680p | C43 | C_0603_1608Metric
470k | R140 | R_0603_1608Metric
10k | R327 | R_0603_1608Metric
Conn_01x01_Female | J71 | TerminalBlock_Keystone_7797
100k | R163 | R_0603_1608Metric
2.2u | C38 | C_0603_1608Metric
100k | R34 | R_0603_1608Metric
100n | CU55 | C_0603_1608Metric
220p | C15 | C_0603_1608Metric
2k | R191 | R_0603_1608Metric
gain_out | TP80 | TestPoint_THTPad_D2.0mm_Drill1.0mm
100k | R255 | R_0603_1608Metric
10k | R316 | R_0603_1608Metric
Conn_01x01_Female | J56 | TerminalBlock_Keystone_7797
Conn_01x01_Female | J67 | TerminalBlock_Keystone_7797
10k | R195 | R_0603_1608Metric
470k | R201 | R_0603_1608Metric
100n | CU115 | C_0603_1608Metric
100k | R261 | R_0603_1608Metric
SW_DPDT_x2 | SW114 | SW_standard_DPDT_MTS
0 | R83 | R_0603_1608Metric
100k | R285 | R_0603_1608Metric
470k | R244 | R_0603_1608Metric
10k | R76 | R_0603_1608Metric
10k | R328 | R_0603_1608Metric
10u | C144 | C_0805_2012Metric
430 | R264 | R_0603_1608Metric
100k | R155 | R_0603_1608Metric
2.2u | C42 | C_0603_1608Metric
comp_out_b | TP50 | TestPoint_THTPad_D2.0mm_Drill1.0mm
100n | CU48 | C_0603_1608Metric
0 | R135 | R_0603_1608Metric
diff_out | TP23 | TestPoint_THTPad_D2.0mm_Drill1.0mm
100n | CU54 | C_0603_1608Metric
SW_DPDT_x2 | SW505 | SW_standard_DPDT_MTS
680p | C79 | C_0603_1608Metric
100k | R21 | R_0603_1608Metric
220p | C89 | C_0603_1608Metric
2.2u | C68 | C_0603_1608Metric
100n | CU109 | C_0603_1608Metric
100k | R92 | R_0603_1608Metric
diff_out | TP4 | TestPoint_THTPad_D2.0mm_Drill1.0mm
100k | R189 | R_0603_1608Metric
AudioJack2_SwitchT | J25 | Jack_3.5mm_QingPu_WQP-PJ301M-12_Vertical
Conn_01x01_Female | J10 | TerminalBlock_Keystone_7797
100n | CU10 | C_0603_1608Metric
MountingHole | TP88 | MountingHole_4.3mm_M4
100n | CU64 | C_0603_1608Metric
diff_out | TP30 | TestPoint_THTPad_D2.0mm_Drill1.0mm
10k | R128 | R_0603_1608Metric
100k | R174 | R_0603_1608Metric
100n | CU111 | C_0603_1608Metric
100k | R44 | R_0603_1608Metric
100k | R103 | R_0603_1608Metric
5A/120Ohm | FB17 | C_0805_2012Metric
ADJ | R152 | R_0603_1608Metric
2.2u | C80 | C_0603_1608Metric
220p | C137 | C_0603_1608Metric
SW_DPDT_x2 | SW306 | SW_standard_DPDT_MTS
100k | R35 | R_0603_1608Metric
1u | C99 | C_0603_1608Metric
47p | C83 | C_0603_1608Metric
Conn_01x01_Female | J73 | TerminalBlock_Keystone_7797
100k | R245 | R_0603_1608Metric
10k | R93 | R_0603_1608Metric
0 | R109 | R_0603_1608Metric
comp_out_b | TP29 | TestPoint_THTPad_D2.0mm_Drill1.0mm
22n | C21 | C_0603_1608Metric
220p | C140 | C_0603_1608Metric
100n | CU18 | C_0603_1608Metric
100k | R55 | R_0603_1608Metric
100n | CU94 | C_0603_1608Metric
100n | CU41 | C_0603_1608Metric
430 | R160 | R_0603_1608Metric
100n | CU27 | C_0603_1608Metric
SW_SPDT | SW2 | SW_submini_SPST
Power_Resistor | DNP10 | R_Axial_Power_L50.0mm_W9.0mm_P55.88mm
100k | R190 | R_0603_1608Metric
100n | CU86 | C_0603_1608Metric
100n | CU8 | C_0603_1608Metric
100k | R307 | R_0603_1608Metric
10k | R1 | R_0603_1608Metric
diff_out_b | TP5 | TestPoint_THTPad_D2.0mm_Drill1.0mm
100n | CU69 | C_0603_1608Metric
100n | CU61 | C_0603_1608Metric
100n | CU29 | C_0603_1608Metric
2.2u | C6 | C_0603_1608Metric
470k | R270 | R_0603_1608Metric
220p | C13 | C_0603_1608Metric
100n | CU25 | C_0603_1608Metric
1u | C9 | C_0603_1608Metric
100n | CU57 | C_0603_1608Metric
LED_Dual_KAK | D121 | LED_D3.0mm-3
100n | CU21 | C_0603_1608Metric
100k | R120 | R_0603_1608Metric
510 | R159 | R_0603_1608Metric
100k | R111 | R_0603_1608Metric
Conn_01x01_Female | J55 | TerminalBlock_Keystone_7797
1.5u | C58 | C_0603_1608Metric
2k | R295 | R_0603_1608Metric
AudioJack2_SwitchT | J27 | Jack_3.5mm_QingPu_WQP-PJ301M-12_Vertical
5A/120Ohm | FB11 | C_0805_2012Metric
SW_SPDT | SW33 | SW_submini_SPST
2.2u | C50 | C_0603_1608Metric
20k | R12 | R_0603_1608Metric
Conn_01x01_Female | J72 | TerminalBlock_Keystone_7797
680p | C8 | C_0603_1608Metric
100k | R267 | R_0603_1608Metric
100n | CU95 | C_0603_1608Metric
PD_out | TP11 | TestPoint_THTPad_D2.0mm_Drill1.0mm
100k | R179 | R_0603_1608Metric
SW_SPDT | SW41 | SW_submini_SPST
1u | C97 | C_0603_1608Metric
SW_SPDT | SW10 | SW_submini_SPST
100k | R277 | R_0603_1608Metric
comp_out_a | TP27 | TestPoint_THTPad_D2.0mm_Drill1.0mm
5A/120Ohm | FB7 | C_0805_2012Metric
100k | R147 | R_0603_1608Metric
100n | CU53 | C_0603_1608Metric
1u | C133 | C_0603_1608Metric
1u | C17 | C_0603_1608Metric
100n | CU19 | C_0603_1608Metric
gain_out | TP99 | TestPoint_THTPad_D2.0mm_Drill1.0mm
10k | R301 | R_0603_1608Metric
10u | C142 | C_0805_2012Metric
Conn_01x01_Female | J15 | TerminalBlock_Keystone_7797
diff_out | TP44 | TestPoint_THTPad_D2.0mm_Drill1.0mm
100k | R8 | R_0603_1608Metric
220p | C139 | C_0603_1608Metric
100n | CU71 | C_0603_1608Metric
100n | CU68 | C_0603_1608Metric
ADJ | R204 | R_0603_1608Metric
comp_out_a | TP69 | TestPoint_THTPad_D2.0mm_Drill1.0mm
10k | R326 | R_0603_1608Metric
gain_out | TP101 | TestPoint_THTPad_D2.0mm_Drill1.0mm
2k | R87 | R_0603_1608Metric
470k | R16 | R_0603_1608Metric
100k | R7 | R_0603_1608Metric
5A/120Ohm | FB23 | C_0805_2012Metric
100n | CU114 | C_0603_1608Metric
680p | C49 | C_0603_1608Metric
0 | R27 | R_0603_1608Metric
diff_out_b | TP84 | TestPoint_THTPad_D2.0mm_Drill1.0mm
470k | R192 | R_0603_1608Metric
5A/120Ohm | FB20 | C_0805_2012Metric
1u | C87 | C_0603_1608Metric
10k | R321 | R_0603_1608Metric
100k | R141 | R_0603_1608Metric
1k | R124 | R_0603_1608Metric
100k | R199 | R_0603_1608Metric
gain_out | TP59 | TestPoint_THTPad_D2.0mm_Drill1.0mm
22n | C51 | C_0603_1608Metric
Power_Resistor | DNP3 | R_Axial_Power_L50.0mm_W9.0mm_P55.88mm
SW_SPDT | SW25 | SW_submini_SPST
100n | CU107 | C_0603_1608Metric
100n | CU30 | C_0603_1608Metric
100n | CU7 | C_0603_1608Metric
1.5u | C52 | C_0603_1608Metric
1u | C105 | C_0603_1608Metric
100k | R271 | R_0603_1608Metric
100n | CU80 | C_0603_1608Metric
430 | R238 | R_0603_1608Metric
diff_out | TP58 | TestPoint_THTPad_D2.0mm_Drill1.0mm
100k | R89 | R_0603_1608Metric
Conn_01x01_Female | J62 | TerminalBlock_Keystone_7797
100k | R268 | R_0603_1608Metric
2.2u | C66 | C_0603_1608Metric
20k | R156 | R_0603_1608Metric
100n | CU70 | C_0603_1608Metric
LED_Dual_KAK | D37 | LED_D3.0mm-3
430 | R82 | R_0603_1608Metric
430 | R290 | R_0603_1608Metric
100n | CU98 | C_0603_1608Metric
2k | R113 | R_0603_1608Metric
100k | R242 | R_0603_1608Metric
47p | C3 | C_0603_1608Metric
100k | R183 | R_0603_1608Metric
Power_Resistor | DNP12 | R_Axial_Power_L50.0mm_W9.0mm_P55.88mm
100k | R79 | R_0603_1608Metric
100k | R300 | R_0603_1608Metric
100n | CU96 | C_0603_1608Metric
gain_out | TP102 | TestPoint_THTPad_D2.0mm_Drill1.0mm
100n | CU119 | C_0603_1608Metric
1.5u | C22 | C_0603_1608Metric
SW_SPDT | SW9 | SW_submini_SPST
100k | R172 | R_0603_1608Metric
100n | CU82 | C_0603_1608Metric
LED_Dual_KAK | D25 | LED_D3.0mm-3
430 | R57 | R_0603_1608Metric
1u | C109 | C_0603_1608Metric
1.5u | C34 | C_0603_1608Metric
gain_out | TP66 | TestPoint_THTPad_D2.0mm_Drill1.0mm
10k | R30 | R_0603_1608Metric
10u | C18 | C_0805_2012Metric
470k | R123 | R_0603_1608Metric
SW_DPDT_x2 | SW206 | SW_standard_DPDT_MTS
gain_out | TP100 | TestPoint_THTPad_D2.0mm_Drill1.0mm
100k | R229 | R_0603_1608Metric
gain_out | TP98 | TestPoint_THTPad_D2.0mm_Drill1.0mm
10k | R154 | R_0603_1608Metric
10k | R11 | R_0603_1608Metric
100n | CU15 | C_0603_1608Metric
diff_out_a | TP54 | TestPoint_THTPad_D2.0mm_Drill1.0mm
Conn_01x12_Female | J74 | PinHeader_1x12_P2.54mm_Vertical
100n | CU1 | C_0603_1608Metric
10k | R275 | R_0603_1608Metric
100k | R60 | R_0603_1608Metric
100k | R224 | R_0603_1608Metric
Conn_01x01_Female | J70 | TerminalBlock_Keystone_7797
PD_out | TP39 | TestPoint_THTPad_D2.0mm_Drill1.0mm
220p | C103 | C_0603_1608Metric
220p | C126 | C_0603_1608Metric
100k | R281 | R_0603_1608Metric
SW_DPDT_x2 | SW14 | SW_standard_DPDT_MTS
10k | R117 | R_0603_1608Metric
100k | R184 | R_0603_1608Metric
ADJ | R282 | R_0603_1608Metric
100n | CU31 | C_0603_1608Metric
0 | R214 | R_0603_1608Metric
220p | C16 | C_0603_1608Metric
470k | R63 | R_0603_1608Metric
100k | RV40 | Potentiometer_Bourns_PTV09A-1_Single_Vertical
LED_Dual_KAK | D61 | LED_D3.0mm-3
AudioJack2_SwitchT | J19 | Jack_3.5mm_QingPu_WQP-PJ301M-12_Vertical
1u | C141 | C_0603_1608Metric
100k | R144 | R_0603_1608Metric
10u | C118 | C_0805_2012Metric
AudioJack2_SwitchT | J45 | Jack_3.5mm_QingPu_WQP-PJ301M-12_Vertical
100k | R129 | R_0603_1608Metric
100k | R193 | R_0603_1608Metric
470k | R298 | R_0603_1608Metric
100n | CU100 | C_0603_1608Metric
1k | R47 | R_0603_1608Metric
100n | CU91 | C_0603_1608Metric
comp_out_a | TP48 | TestPoint_THTPad_D2.0mm_Drill1.0mm
430 | R212 | R_0603_1608Metric
100n | CU63 | C_0603_1608Metric
10k | R68 | R_0603_1608Metric
LED_Dual_KAK | D97 | LED_D3.0mm-3
MountingHole | TP6 | MountingHole_4.3mm_M4_DIN965_Pad
SW_DPDT_x2 | SW34 | SW_standard_DPDT_MTS
comp_out_b | TP71 | TestPoint_THTPad_D2.0mm_Drill1.0mm
100k | R219 | R_0603_1608Metric
SW_SPDT | SW35 | SW_submini_SPST
100n | CU5 | C_0603_1608Metric
SW_SPDT | SW42 | SW_submini_SPST
100k | R297 | R_0603_1608Metric
430 | R186 | R_0603_1608Metric
PD_out | TP74 | TestPoint_THTPad_D2.0mm_Drill1.0mm
470k | R166 | R_0603_1608Metric
0 | R291 | R_0603_1608Metric
47p | C29 | C_0603_1608Metric
gain_out | TP10 | TestPoint_THTPad_D2.0mm_Drill1.0mm
diff_out_a | TP68 | TestPoint_THTPad_D2.0mm_Drill1.0mm
1k | R280 | R_0603_1608Metric
Power_Resistor | DNP1 | R_Axial_Power_L50.0mm_W9.0mm_P55.88mm
SW_SPDT | SW20 | SW_submini_SPST
100k | R137 | R_0603_1608Metric
470k | R142 | R_0603_1608Metric
22n | C81 | C_0603_1608Metric
5A/120Ohm | FB4 | C_0805_2012Metric
10k | R319 | R_0603_1608Metric
2.2u | C56 | C_0603_1608Metric
100n | CU81 | C_0603_1608Metric
1u | C129 | C_0603_1608Metric
2k | R139 | R_0603_1608Metric
diff_out_a | TP19 | TestPoint_THTPad_D2.0mm_Drill1.0mm
Conn_01x01_Female | J53 | TerminalBlock_Keystone_7797
Conn_01x01_Female | J11 | TerminalBlock_Keystone_7797
SW_SPDT | SW8 | SW_submini_SPST
5A/120Ohm | FB3 | C_0805_2012Metric
100k | R122 | R_0603_1608Metric
220p | C138 | C_0603_1608Metric
100k | R43 | R_0603_1608Metric
100n | CU28 | C_0603_1608Metric
20k | R286 | R_0603_1608Metric
gain_out | TP97 | TestPoint_THTPad_D2.0mm_Drill1.0mm
100n | CU56 | C_0603_1608Metric
2k | R269 | R_0603_1608Metric
470k | R46 | R_0603_1608Metric
20k | R53 | R_0603_1608Metric
AudioJack2_SwitchT | J16 | Jack_3.5mm_QingPu_WQP-PJ301M-12_Vertical
100k | R127 | R_0603_1608Metric
10k | R221 | R_0603_1608Metric
47p | C77 | C_0603_1608Metric
1u | C111 | C_0603_1608Metric
680p | C4 | C_0603_1608Metric
470k | R71 | R_0603_1608Metric
470k | R149 | R_0603_1608Metric
100k | R45 | R_0603_1608Metric
AudioJack2_SwitchT | J201 | Jack_3.5mm_QingPu_WQP-PJ301M-12_Vertical
2k | R217 | R_0603_1608Metric
100n | CU16 | C_0603_1608Metric
diff_out_a | TP75 | TestPoint_THTPad_D2.0mm_Drill1.0mm
100k | R236 | R_0603_1608Metric
diff_out_b | TP63 | TestPoint_THTPad_D2.0mm_Drill1.0mm
100k | R231 | R_0603_1608Metric
diff_out_b | TP49 | TestPoint_THTPad_D2.0mm_Drill1.0mm
Conn_01x01_Female | J57 | TerminalBlock_Keystone_7797
100k | R209 | R_0603_1608Metric
2.2u | C78 | C_0603_1608Metric
100k | R304 | R_0603_1608Metric
diff_out_b | TP21 | TestPoint_THTPad_D2.0mm_Drill1.0mm
100k | R283 | R_0603_1608Metric
100k | R41 | R_0603_1608Metric
10k | R42 | R_0603_1608Metric
100k | R207 | R_0603_1608Metric
2.2u | C48 | C_0603_1608Metric
470k | R37 | R_0603_1608Metric
100k | R112 | R_0603_1608Metric
220p | C90 | C_0603_1608Metric
430 | R31 | R_0603_1608Metric
100n | CU24 | C_0603_1608Metric
5A/120Ohm | FB22 | C_0805_2012Metric
0 | R33 | R_0603_1608Metric
AudioJack2_SwitchT | J39 | Jack_3.5mm_QingPu_WQP-PJ301M-12_Vertical
diff_out_b | TP35 | TestPoint_THTPad_D2.0mm_Drill1.0mm
1k | R202 | R_0603_1608Metric
SW_DPDT_x2 | SW405 | SW_standard_DPDT_MTS
0 | R84 | R_0603_1608Metric
100n | CU46 | C_0603_1608Metric
diff_out_a | TP47 | TestPoint_THTPad_D2.0mm_Drill1.0mm
Conn_01x03_Male | J54 | PinHeader_1x03_P2.54mm_Vertical
100k | R151 | R_0603_1608Metric
SW_SPDT | SW37 | SW_submini_SPST
100k | R96 | R_0603_1608Metric
100n | CU112 | C_0603_1608Metric
diff_out_b | TP14 | TestPoint_THTPad_D2.0mm_Drill1.0mm
470k | R218 | R_0603_1608Metric
100k | RV16 | Potentiometer_Bourns_PTV09A-1_Single_Vertical
100k | R13 | R_0603_1608Metric
SW_SPDT | SW19 | SW_submini_SPST
100k | R77 | R_0603_1608Metric
510 | R237 | R_0603_1608Metric
2.2u | C5 | C_0603_1608Metric
100k | R157 | R_0603_1608Metric
comp_out_b | TP64 | TestPoint_THTPad_D2.0mm_Drill1.0mm
AudioJack2_SwitchT | J37 | Jack_3.5mm_QingPu_WQP-PJ301M-12_Vertical
100k | R200 | R_0603_1608Metric
20k | R130 | R_0603_1608Metric
220p | C127 | C_0603_1608Metric
100n | CU76 | C_0603_1608Metric
680p | C31 | C_0603_1608Metric
10u | C132 | C_0805_2012Metric
470k | R227 | R_0603_1608Metric
SW_SPDT | SW11 | SW_submini_SPST
2.2u | C84 | C_0603_1608Metric
SW_DPDT_x2 | SW64 | SW_standard_DPDT_MTS
10k | R51 | R_0603_1608Metric
100k | R105 | R_0603_1608Metric
220p | C102 | C_0603_1608Metric
100n | CU105 | C_0603_1608Metric
comp_out_b | TP78 | TestPoint_THTPad_D2.0mm_Drill1.0mm
100k | R121 | R_0603_1608Metric
100n | CU101 | C_0603_1608Metric
100n | CU75 | C_0603_1608Metric
100k | R94 | R_0603_1608Metric
10k | R325 | R_0603_1608Metric
100k | R95 | R_0603_1608Metric
47p | C59 | C_0603_1608Metric
100k | R248 | R_0603_1608Metric
10u | C106 | C_0805_2012Metric
1u | C117 | C_0603_1608Metric
680p | C61 | C_0603_1608Metric
1u | C135 | C_0603_1608Metric
1u | C98 | C_0603_1608Metric
5A/120Ohm | FB2 | C_0805_2012Metric
120 | R333 | R_0603_1608Metric
Conn_01x01_Female | J58 | TerminalBlock_Keystone_7797
100n | CU103 | C_0603_1608Metric
220p | C104 | C_0603_1608Metric
1u | C10 | C_0603_1608Metric
SW_SPDT | SW39 | SW_submini_SPST
0 | R265 | R_0603_1608Metric
Conn_01x01_Female | J7 | TerminalBlock_Keystone_7797
100k | R132 | R_0603_1608Metric
2.2u | C30 | C_0603_1608Metric
5A/120Ohm | FB6 | C_0805_2012Metric
MountingHole | TP90 | MountingHole_4.3mm_M4
1k | R72 | R_0603_1608Metric
MountingHole | TP87 | MountingHole_4.3mm_M4_DIN965_Pad
100n | CU85 | C_0603_1608Metric
100n | CU44 | C_0603_1608Metric
SW_SPDT | SW15 | SW_submini_SPST
470k | R272 | R_0603_1608Metric
1u | C107 | C_0603_1608Metric
100n | CU106 | C_0603_1608Metric
PD_out | TP32 | TestPoint_THTPad_D2.0mm_Drill1.0mm
ADJ | R230 | R_0603_1608Metric
100k | R314 | R_0603_1608Metric
100k | RV58 | Potentiometer_Bourns_PTV09A-1_Single_Vertical
100k | R80 | R_0603_1608Metric
100k | R259 | R_0603_1608Metric
220p | C128 | C_0603_1608Metric
SW_DPDT_x2 | SW6 | SW_standard_DPDT_MTS
100k | R274 | R_0603_1608Metric
510 | R3 | R_0603_1608Metric
comp_out_b | TP22 | TestPoint_THTPad_D2.0mm_Drill1.0mm
10k | R232 | R_0603_1608Metric
SW_DPDT_x2 | SW44 | SW_standard_DPDT_MTS
100k | RV70 | Potentiometer_Bourns_PTV09A-1_Single_Vertical
5A/120Ohm | FB1 | C_0805_2012Metric
5A/120Ohm | FB12 | C_0805_2012Metric
diff_out_a | TP40 | TestPoint_THTPad_D2.0mm_Drill1.0mm
comp_out_a | TP7 | TestPoint_THTPad_D2.0mm_Drill1.0mm
ADJ | R308 | R_0603_1608Metric
470k | R90 | R_0603_1608Metric
LED_Dual_KAK | D73 | LED_D3.0mm-3
220p | C101 | C_0603_1608Metric
47p | C23 | C_0603_1608Metric
PD_out | TP81 | TestPoint_THTPad_D2.0mm_Drill1.0mm
1u | C95 | C_0603_1608Metric
100k | R164 | R_0603_1608Metric
1k | R228 | R_0603_1608Metric
100n | CU58 | C_0603_1608Metric
gain_out | TP73 | TestPoint_THTPad_D2.0mm_Drill1.0mm
SW_DPDT_x2 | SW94 | SW_standard_DPDT_MTS
5A/120Ohm | FB10 | C_0805_2012Metric
680p | C25 | C_0603_1608Metric
AudioJack2_SwitchT | J33 | Jack_3.5mm_QingPu_WQP-PJ301M-12_Vertical
100k | R69 | R_0603_1608Metric
220p | C114 | C_0603_1608Metric
100n | CU117 | C_0603_1608Metric
220p | C14 | C_0603_1608Metric
comp_out_a | TP34 | TestPoint_THTPad_D2.0mm_Drill1.0mm
680p | C73 | C_0603_1608Metric
2.2u | C54 | C_0603_1608Metric
100k | R241 | R_0603_1608Metric
comp_out_b | TP8 | TestPoint_THTPad_D2.0mm_Drill1.0mm
1k | R306 | R_0603_1608Metric
SW_DPDT_x2 | SW105 | SW_standard_DPDT_MTS
comp_out_a | TP55 | TestPoint_THTPad_D2.0mm_Drill1.0mm
100k | R106 | R_0603_1608Metric
100k | R196 | R_0603_1608Metric
10k | R29 | R_0603_1608Metric
10k | R324 | R_0603_1608Metric
10k | R223 | R_0603_1608Metric
470k | R19 | R_0603_1608Metric
2.2u | C26 | C_0603_1608Metric
Power_Resistor | DNP8 | R_Axial_Power_L50.0mm_W9.0mm_P55.88mm
ADJ | R256 | R_0603_1608Metric
SW_SPDT | SW31 | SW_submini_SPST
SW_SPDT | SW29 | SW_submini_SPST
100k | R153 | R_0603_1608Metric
220p | C115 | C_0603_1608Metric
10k | R247 | R_0603_1608Metric
470k | R114 | R_0603_1608Metric
1u | C136 | C_0603_1608Metric
SW_SPDT | SW22 | SW_submini_SPST
1k | R2 | R_0603_1608Metric
100k | RV64 | Potentiometer_Bourns_PTV09A-1_Single_Vertical
100n | CU108 | C_0603_1608Metric
100k | R148 | R_0603_1608Metric
22n | C33 | C_0603_1608Metric
5A/120Ohm | FB13 | C_0805_2012Metric
20k | R208 | R_0603_1608Metric
Conn_01x01_Female | J4 | TerminalBlock_Keystone_7797
10k | R320 | R_0603_1608Metric
SW_DPDT_x2 | SW506 | SW_standard_DPDT_MTS
100n | CU37 | C_0603_1608Metric
10u | C96 | C_0805_2012Metric
AudioJack2_SwitchT | J22 | Jack_3.5mm_QingPu_WQP-PJ301M-12_Vertical
AudioJack2_SwitchT | J31 | Jack_3.5mm_QingPu_WQP-PJ301M-12_Vertical
100k | R276 | R_0603_1608Metric
10u | C120 | C_0805_2012Metric
10k | R119 | R_0603_1608Metric
470k | R97 | R_0603_1608Metric
SW_SPDT | SW12 | SW_submini_SPST
AudioJack2_SwitchT | J28 | Jack_3.5mm_QingPu_WQP-PJ301M-12_Vertical
Conn_01x01_Female | J8 | TerminalBlock_Keystone_7797
2.2u | C1 | C_0603_1608Metric
100n | CU74 | C_0603_1608Metric
100n | CU50 | C_0603_1608Metric
220p | C116 | C_0603_1608Metric
100n | CU23 | C_0603_1608Metric
100n | CU67 | C_0603_1608Metric
100k | R146 | R_0603_1608Metric
100n | CU3 | C_0603_1608Metric
100n | CU79 | C_0603_1608Metric
100n | CU102 | C_0603_1608Metric
100k | R170 | R_0603_1608Metric
comp_out_b | TP43 | TestPoint_THTPad_D2.0mm_Drill1.0mm
100k | R233 | R_0603_1608Metric
diff_out | TP16 | TestPoint_THTPad_D2.0mm_Drill1.0mm
5A/120Ohm | FB15 | C_0805_2012Metric
gain_out | TP3 | TestPoint_THTPad_D2.0mm_Drill1.0mm
Conn_01x01_Female | J50 | TerminalBlock_Keystone_7797
510 | R331 | R_0603_1608Metric
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

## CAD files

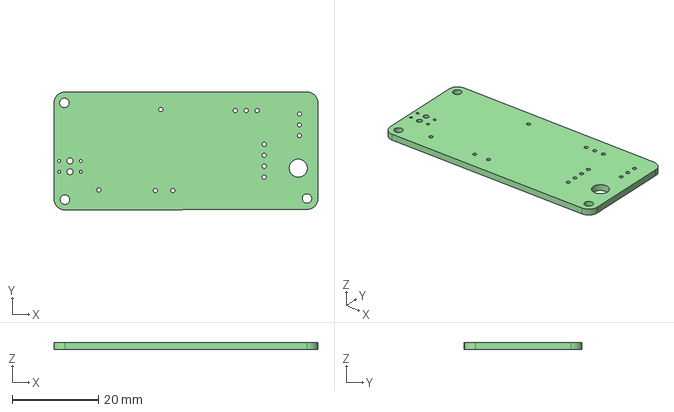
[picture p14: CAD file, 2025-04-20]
Electronics/EM_Harpsichord_ActuatorsV2/EM_Harpsichord_Sustainer+Playback_V2.0/EM_Harpsichord_Sustainer+Playback_V2.0.step
61.2 x 27.4 x 1.60 mm

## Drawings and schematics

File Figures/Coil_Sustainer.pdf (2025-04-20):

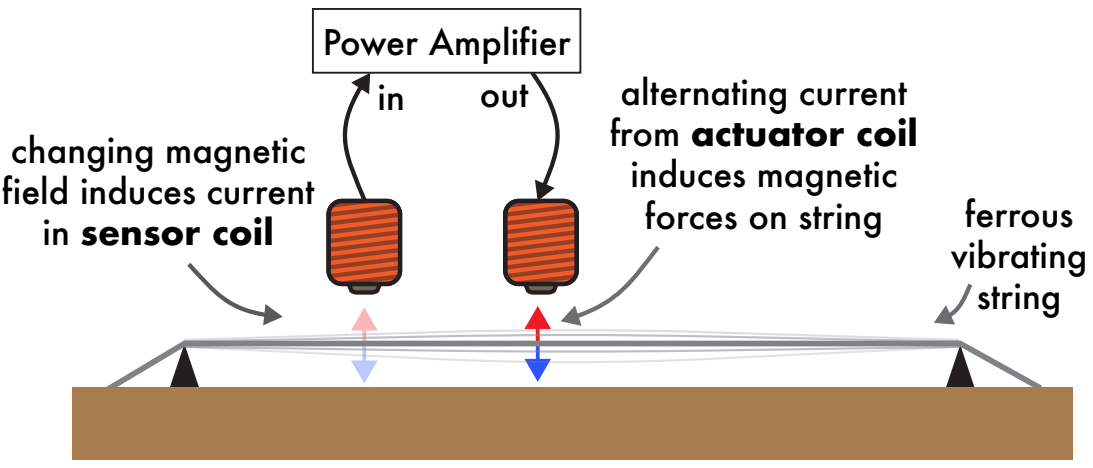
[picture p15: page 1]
Power Amplifier; forces on string; ferrous; vibrating string; out

alternating current
from actuator coil
induces magnetic

changing magnetic
field induces current
in sensor coil

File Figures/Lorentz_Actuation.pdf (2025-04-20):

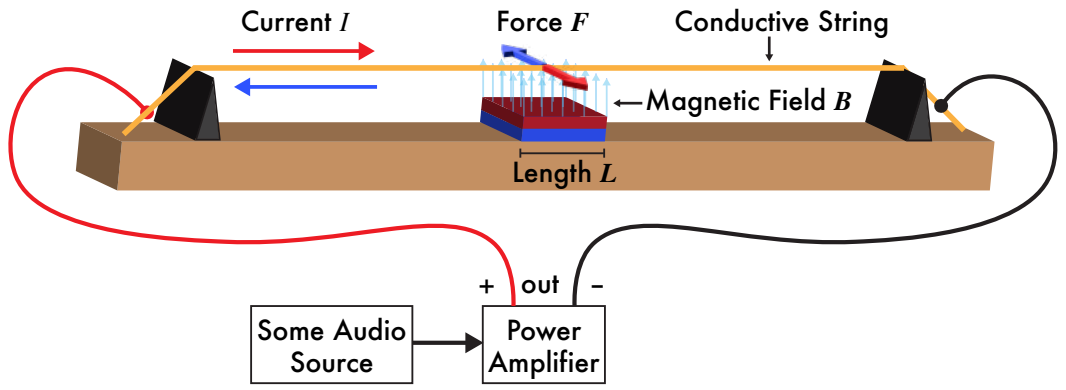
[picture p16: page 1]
permanent magnet; Force F; Conductive String; Power Amplifier; Some Audio Source; + out –; Current I; Magnetic Field B; Length L

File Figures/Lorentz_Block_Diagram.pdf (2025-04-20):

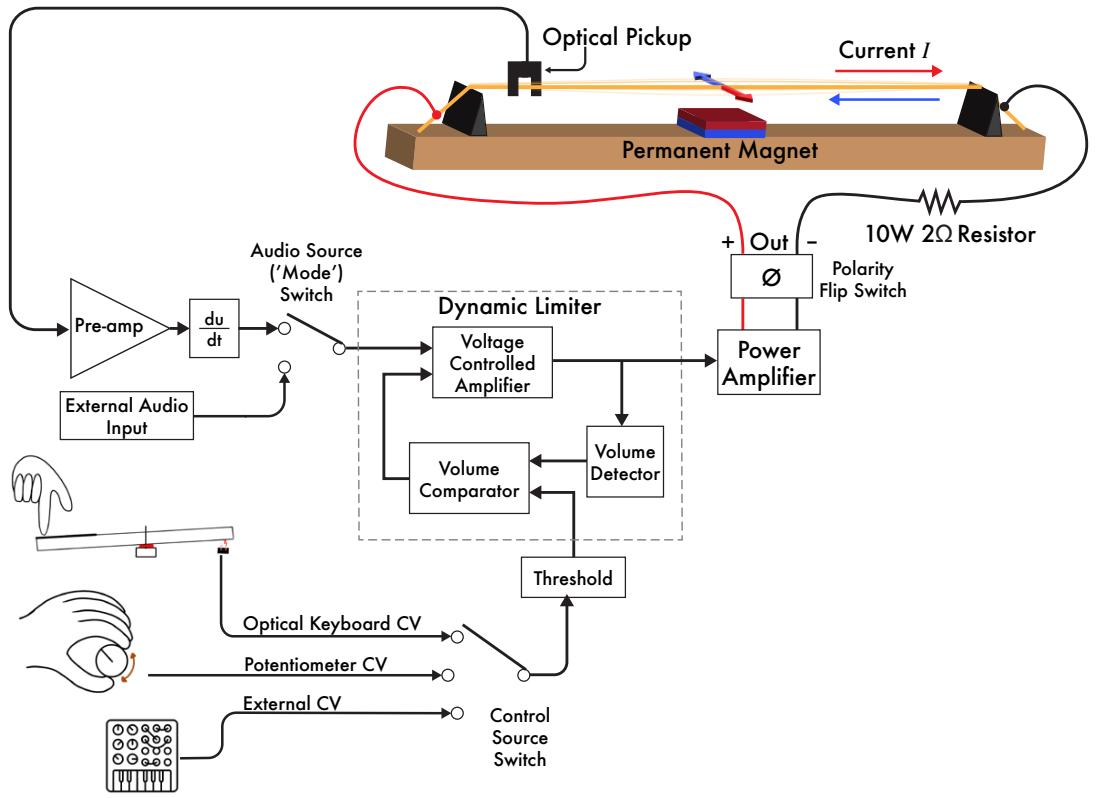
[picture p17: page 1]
External Audio Input; Polarity; Flip Switch; Control Source Switch; Audio Source (ʼModeʼ) Switch; Permanent Magnet; Power Amplifier; + Out –; 10W 2Ω Resistor; dt Pre-amp; Voltage; Controlled Amplifier; Volume; Detector; Comparator; Threshold; Dynamic Limiter

Current I Optical Pickup

Optical Keyboard CV
Potentiometer CV
External CV

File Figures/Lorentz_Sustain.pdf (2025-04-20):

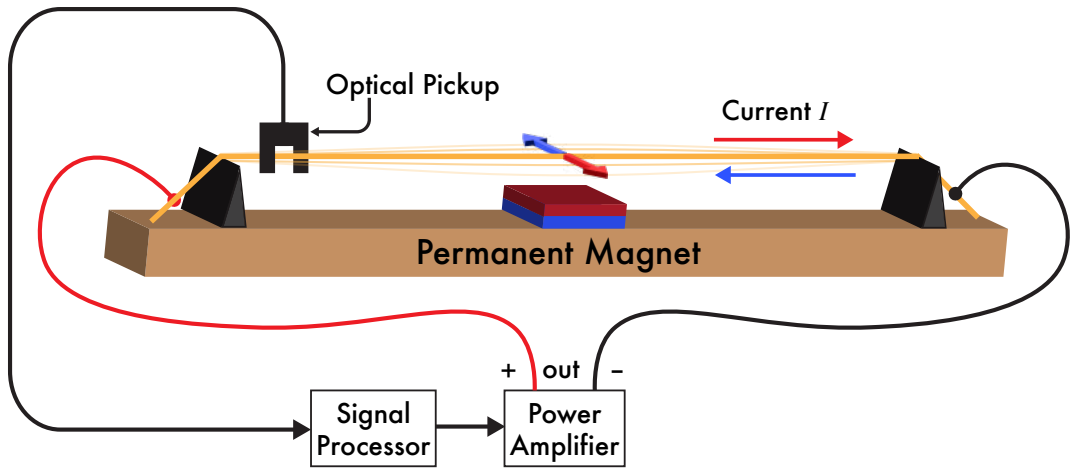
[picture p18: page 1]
Signal Processor; permanent magnet; Power Amplifier; + out –; Current I; Optical Pickup; Permanent Magnet

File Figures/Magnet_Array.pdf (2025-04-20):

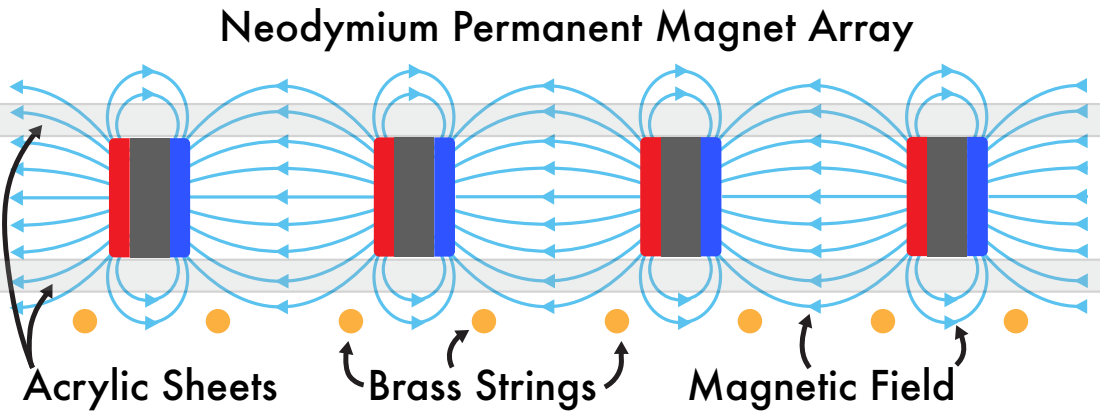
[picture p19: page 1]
Acrylic Sheets; Brass Strings; Magnetic Field

Neodymium Permanent Magnet Array

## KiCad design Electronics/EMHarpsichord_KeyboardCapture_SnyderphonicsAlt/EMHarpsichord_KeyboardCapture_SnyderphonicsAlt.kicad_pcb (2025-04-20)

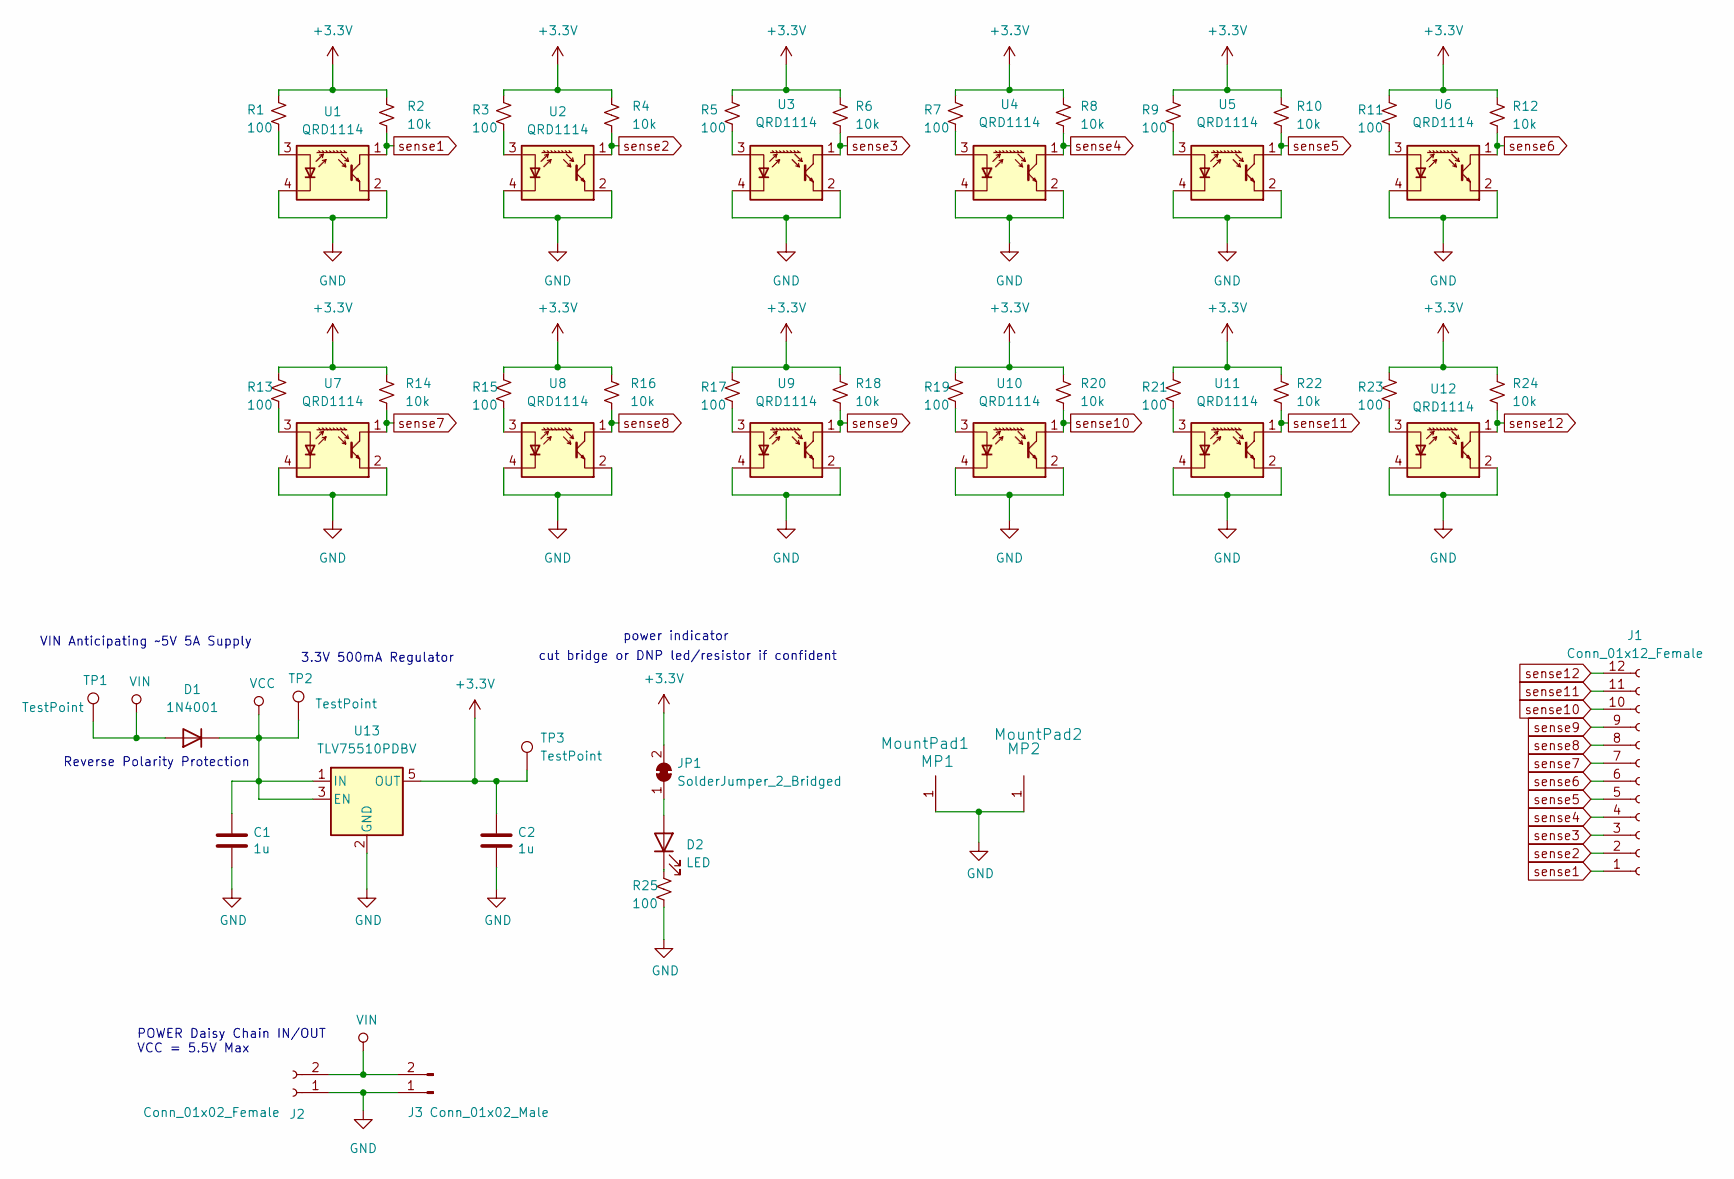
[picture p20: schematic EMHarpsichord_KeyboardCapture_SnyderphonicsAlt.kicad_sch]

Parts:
C1, C2: 1u; C_0603_1608Metric
D1: 1N4001; D_SOD-123
D2: LED; LED_0603_1608Metric
J1: Conn_01x12_Female; PinHeader_1x12_P2.54mm_Vertical
J2: Conn_01x02_Female; PinHeader_1x02_P2.54mm_Vertical
J3: Conn_01x02_Male; PinHeader_1x02_P2.54mm_Vertical
JP1: SolderJumper_2_Bridged; SolderJumper-2_P1.3mm_Bridged_RoundedPad1.0x1.5mm
MP1: MountPad1
MP2: MountPad2
R1, R3, R5, R7, R9, R11, R13, R15, R17, R19, R21, R23, R25: 100; R_0603_1608Metric
R2, R4, R6, R8, R10, R12, R14, R16, R18, R20, R22, R24: 10k; R_0603_1608Metric
TP1, TP2, TP3: TestPoint
U1, U2, U3, U4, U5, U6, U7, U8, U9, U10, U11, U12: QRD1114; OnSemi_QRD1114
U13: TLV75510PDBV; SOT-23-5

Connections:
+3.3V: C2.1, JP1.2 (B), R1.2, R2.2, R3.2, R4.2, R5.2, R6.2, R7.2, R8.2, R9.2, R10.2, R11.2, R12.2, R13.2, R14.2, R15.2, R16.2, R17.2, R18.2, R19.2, R20.2, R21.2, R22.2, R23.2, R24.2, TP3.1, U13.5 (OUT)
GND: C1.2, C2.2, J2.1, J3.1, MP1.1, MP2.1, R25.1, U1.2 (K), U1.4 (E), U2.2 (K), U2.4 (E), U3.2 (K), U3.4 (E), U4.2 (K), U4.4 (E), U5.2 (K), U5.4 (E), U6.2 (K), U6.4 (E), U7.2 (K), U7.4 (E), U8.2 (K), U8.4 (E), U9.2 (K), U9.4 (E), U10.2 (K), U10.4 (E), U11.2 (K), U11.4 (E), U12.2 (K), U12.4 (E), U13.2 (GND)
unnamed: D2.1 (K), R25.2
unnamed: D2.2 (A), JP1.1 (A)
unnamed: R1.1, U1.3 (C)
unnamed: R3.1, U2.3 (C)
unnamed: R5.1, U3.3 (C)
unnamed: R7.1, U4.3 (C)
unnamed: R9.1, U5.3 (C)
unnamed: R11.1, U6.3 (C)
unnamed: R13.1, U7.3 (C)
unnamed: R15.1, U8.3 (C)
unnamed: R17.1, U9.3 (C)
unnamed: R19.1, U10.3 (C)
unnamed: R21.1, U11.3 (C)
unnamed: R23.1, U12.3 (C)
VCC: C1.1, D1.1 (K), TP2.1, U13.1 (IN), U13.3 (EN)
VIN: D1.2 (A), J2.2, J3.2, TP1.1
sense1: J1.1, R2.1, U1.1 (A)
sense2: J1.2, R4.1, U2.1 (A)
sense3: J1.3, R6.1, U3.1 (A)
sense4: J1.4, R8.1, U4.1 (A)
sense5: J1.5, R10.1, U5.1 (A)
sense6: J1.6, R12.1, U6.1 (A)
sense7: J1.7, R14.1, U7.1 (A)
sense8: J1.8, R16.1, U8.1 (A)
sense9: J1.9, R18.1, U9.1 (A)
sense10: J1.10, R20.1, U10.1 (A)
sense11: J1.11, R22.1, U11.1 (A)
sense12: J1.12, R24.1, U12.1 (A)

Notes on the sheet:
3.3V 500mA Regulator
POWER Daisy Chain IN/OUT VCC = 5.5V Max
power indicator
Reverse Polarity Protection
VIN Anticipating ~5V 5A Supply
cut bridge or DNP led/resistor if confident

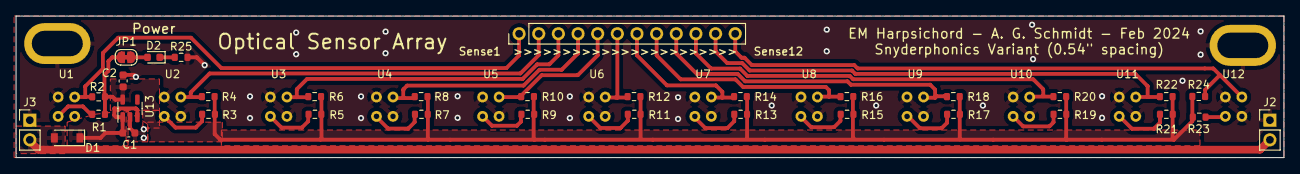
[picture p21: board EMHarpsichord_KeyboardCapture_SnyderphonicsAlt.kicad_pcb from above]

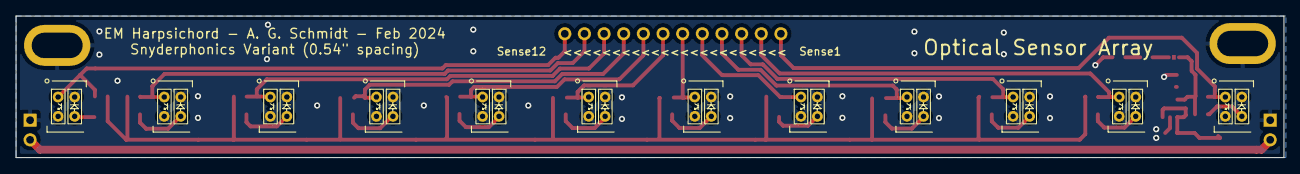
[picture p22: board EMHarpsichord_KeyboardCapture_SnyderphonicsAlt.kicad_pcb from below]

Board: 2 copper layers, 163.9 x 18.3 mm, 48 parts (12 on the bottom side), 30 nets.

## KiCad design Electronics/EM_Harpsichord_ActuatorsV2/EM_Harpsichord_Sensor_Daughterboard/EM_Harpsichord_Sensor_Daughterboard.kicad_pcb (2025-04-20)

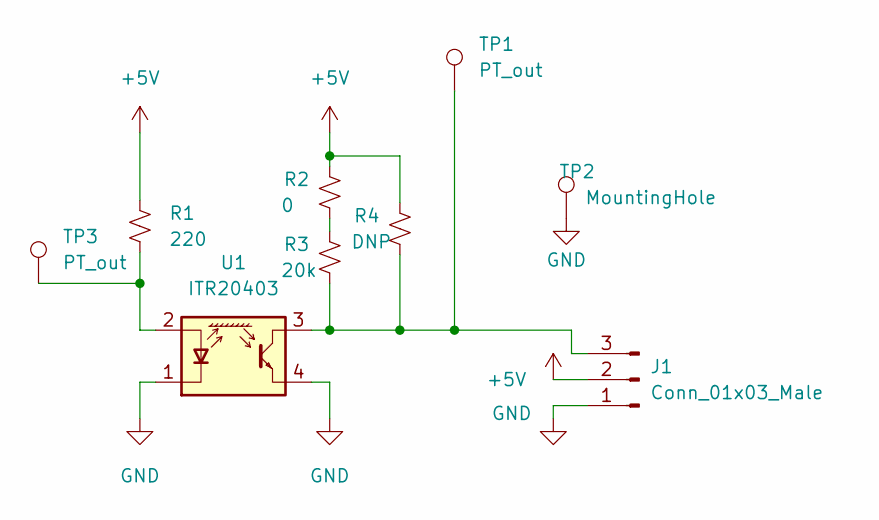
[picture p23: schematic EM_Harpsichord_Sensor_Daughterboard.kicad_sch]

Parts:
J1: Conn_01x03_Male; JST_XH_S3B-XH-A_1x03_P2.50mm_Horizontal; LCSC C161870
R1: 220; R_0603_1608Metric
R2: 0; R_0603_1608Metric
R3: 20k; R_0603_1608Metric
R4: DNP; R_0603_1608Metric
TP1, TP3: PT_out; TestPoint_THTPad_D2.0mm_Drill1.0mm
TP2: MountingHole; TestPoint_THTPad_D2.0mm_Drill1.0mm
U1: ITR20403; Everlight_ITR20403; LCSC C5135

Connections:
+5V: J1.2, R1.1, R2.1, R4.1
GND: J1.1, TP2.1, U1.1 (K), U1.4 (E)
unnamed: J1.3, R3.2, R4.2, TP1.1, U1.3 (C)
unnamed: R1.2, TP3.1, U1.2 (A)
unnamed: R2.2, R3.1

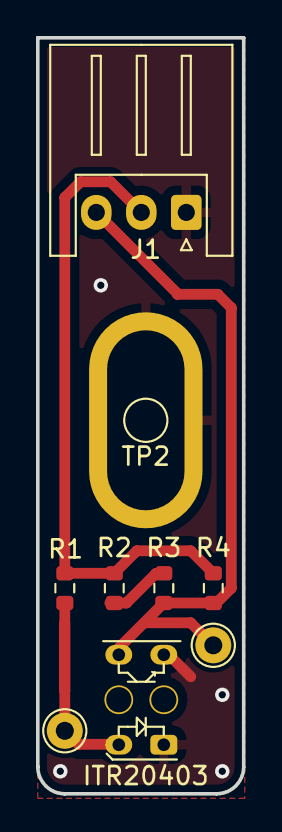
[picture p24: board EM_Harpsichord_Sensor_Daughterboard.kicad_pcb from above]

Board: 2 copper layers, 11.4 x 42.0 mm, 9 parts (0 on the bottom side), 5 nets.

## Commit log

2025-04-20 Initial Commit
    Plenty of sorting to do. Initial commit before I accidentally delete/move something I didn't mean to
    [BOM-EMHarpsichord_KeyboardCapture.csv, BOM-EMHarpsichord_KeyboardCapture_SnyderphonicsAlt.csv, BOM-EMHarpsichord_Sustainer+Playback.csv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]
2025-04-20 Cleaning up
    cleaning up
    [EM_Harpscihord_Channel.kicad_sch, EM_Harpsichord_Amplifier.kicad_sch, EM_Harpsichord_Sustainer+Playback_V2.0.kicad_sch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]
